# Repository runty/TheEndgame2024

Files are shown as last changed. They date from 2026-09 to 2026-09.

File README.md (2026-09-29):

# Endgame — nice!nano wireless / Choc V1 & V2

A 36-key wireless adaptation of [OldMan6955's Endgame](https://github.com/OldMan6955/TheEndgame2024), using **nice!nano v2**, Choc V1/V2 hot-swap switches, a directly soldered **401730 battery**, and one **WS2812B-V6 status LED**.

The current revision is **4 mm wider than the original PCB**. Each key half moves outward 2 mm, giving the inner keys more clearance from the controller while preserving the original outer borders. The controller, battery opening, and LED remain on the board's centreline. The matching case is wider but retains the original height and sloped profile.

**Status:** verified digital prototype. Electrical, manufacturing-file, and CAD checks pass; physical assembly and electrical operation have not been tested. The current Gerber package has not been verified in JLCPCB's upload preview.

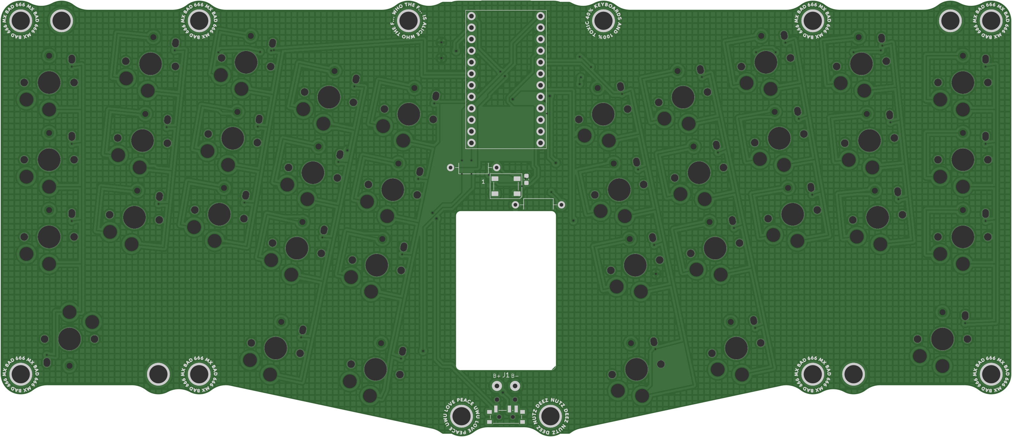
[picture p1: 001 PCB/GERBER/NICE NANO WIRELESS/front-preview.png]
Current PCB, front


## Downloads

Use the PCB, case, and firmware from this table together. The original case and the older XIAO/wired files are separate revisions.

| File | Download |
| --- | --- |
| JLCPCB manufacturing package | [223 mm through-hole-resistor Gerber ZIP](001%20PCB/GERBER/NICE%20NANO%20WIRELESS/TheEndgame2024_NiceNano_223mm_THT_JLCPCB.zip) |
| Widened case | [STL](002%20CASE/NICE%20NANO%20WIRELESS/TheENDGAME2024_NICE_NANO_CASE.stl) · [STEP](002%20CASE/NICE%20NANO%20WIRELESS/TheENDGAME2024_NICE_NANO_CASE.step) |
| Removable battery tray | [STL](002%20CASE/NICE%20NANO%20WIRELESS/TheENDGAME2024_NICE_NANO_BATTERY_TRAY.stl) · [STEP](002%20CASE/NICE%20NANO%20WIRELESS/TheENDGAME2024_NICE_NANO_BATTERY_TRAY.step) |
| Editable KiCad project | [PCB](001%20PCB/KICAD/NICE%20NANO%20WIRELESS/TheEndgame2024_NiceNano.kicad_pcb) · [schematic](001%20PCB/KICAD/NICE%20NANO%20WIRELESS/TheEndgame2024_NiceNano.kicad_sch) · [project and local libraries](001%20PCB/KICAD/NICE%20NANO%20WIRELESS/) |
| nice!nano v2 firmware | [UF2](003%20FIRMWARE/zmk-endgame-nice-nano/firmware/endgame-nice-nano-v2.uf2) · [ZMK source](003%20FIRMWARE/zmk-endgame-nice-nano/) |
| Build details | [Full BOM and assembly notes](docs/nice-nano-wireless.md) · [electrical](docs/nice-nano-electrical.md) · [case](docs/nice-nano-case.md) · [firmware](docs/nice-nano-firmware.md) |

## JLCPCB order settings

| Setting | Value |
| --- | --- |
| Dimensions to enter | **223.00 × 96.11 mm** |
| Layers | **2** |
| Material | **FR-4** |
| Board thickness | **1.6 mm** |
| Copper weight | **1 oz** |

The measured Gerber outline is **223.000032 × 96.106067 mm**. Upload the ZIP intact: it contains the seven board layers, separate plated/non-plated drill files, and the Gerber job file. The **22 × 35 mm battery opening** is included as an internal routed contour. If dimensions need to be entered manually, use the rounded values above and check the board outline and battery opening in the preview.

## Fit and clearance

| Feature | Current design |
| --- | --- |
| Key field | 36 Choc V1/V2 hot-swap positions; each half moved outward 2 mm |
| Outer left/right 1U cap borders | **2.00 mm**, matching the original PCB with 17.5 × 16.5 mm caps |
| Keycap-to-controller clearance | **2.16 mm minimum** to the conservative 18 × 33 mm nice!nano envelope in CAD |
| Printed case width | **231 mm**, with the original overall height retained |
| Battery opening | **22 × 35 mm**, with 1 mm corner radii |
| Battery allowance checked | **18.5 × 33 × 5 mm** complete-pack envelope |

A centred **17 × 30 mm** battery leaves **2.5 mm on each side of the PCB opening**. The larger checked pack envelope leaves **1.75 mm per side and 1.0 mm at each end**, with **0.15 mm above the 5 mm-thick envelope** inside the case after the planned 0.2 mm support allowance. The actual wrapped battery and its lead exit still need measurement.

All 36 nominal **17.5 × 16.5 mm Chicago Steno 1U keycap envelopes** clear the case throughout a full-height CAD sweep, with a **0.70 mm minimum gap**. Choc V2 requires **MX-stem** keycaps. Larger thumb caps and actual print tolerances are not established by this rectangular-envelope check.

See the [measured layout and centreline](docs/validation/nice-nano-pcb/outer-key-symmetry.png), [keycap clearance comparison](docs/validation/nice-nano-case/cs-clearance.png), and [case preview](002%20CASE/NICE%20NANO%20WIRELESS/case-and-tray-preview.png).

## Electronics and assembly

- **nice!nano v2:** mount on short soldered posts, with USB facing the upper edge. Follow the [assembly-height limits](docs/nice-nano-case.md); standard sockets have not been qualified for this case.
- **Battery:** generic 401730 single-cell LiPo, target capacity ≤200 mAh. Solder its wires directly to **J1: pad 1 B+, pad 2 B−**. No JST connector is used. SW38 remains the physical battery disconnect.
- **Resistors:** R1 **330 Ω** and R2 **100 kΩ**, ordinary **¼ W axial through-hole** parts. Use nominal 6.3 × 2.5 mm bodies at **10.16 mm lead pitch**, mounted flat on the PCB's top side. The case accommodates bodies up to 6.5 × 2.5 mm; installation and lead-trimming limits are in the [BOM](docs/nice-nano-wireless.md#parts-and-assembly).
- **Status LED:** one **Worldsemi WS2812B-V6**, powered through nice!nano v2 switched VCC. The translucent case roof acts as the diffuser. The firmware adapts [zmk-rgbled-widget](https://github.com/caksoylar/zmk-rgbled-widget) for brief battery and Bluetooth/USB status flashes, then switches LED power off. See [LED meanings and limits](docs/nice-nano-firmware.md#status-indications).
- **Other parts:** C1 remains a **100 nF 0603 capacitor**, and the matrix retains **36 SOD-123 diodes and 36 Choc hot-swap sockets**. This is a hot-swap switch design; the original optional direct-solder switch pattern is not retained.

The [full parts list](docs/nice-nano-wireless.md#parts-and-assembly) includes controller posts, inserts, tray screws, feet, battery-fit assumptions, and charging requirements. Firmware is **ZMK for nice!nano v2**; the original wired QMK/Vial firmware does not apply to this revision.

## Verification

- **KiCad ERC, DRC, and schematic parity:** zero reported violations or unconnected items under the recorded rules. [ERC](docs/validation/nice-nano-schematic/erc.json) · [DRC](docs/validation/nice-nano-pcb/drc.json)
- **Independent Gerber parsing:** seven board layers, **226 plated and 148 non-plated holes/slots**, both contours closed, and drill registration checked against the PCB source. [Report](docs/validation/nice-nano-pcb/gerbers.json)
- **Mechanical checks:** mirrored key placement, preserved outer borders, centred electronics, valid single-solid STEP parts, watertight STL files, and component/keycap clearance checks. [Spacing](docs/validation/nice-nano-pcb/spacing.json) · [case](docs/validation/nice-nano-case/geometry.json)
- **Firmware:** pinned ZMK build and LED encoder host checks pass. Hardware timing, charging, RF, and full keyboard operation remain untested. [Build and bring-up notes](docs/nice-nano-firmware.md)

The committed PCB is the authoritative manufacturing source. The scratch PCB generator is not a replacement for the finished routing. The [artifact manifest](docs/validation/nice-nano-artifacts.json) records source and output checksums.

## Earlier revisions

| Revision | Details |
| --- | --- |
| XIAO nRF52840 wireless prototype | [Handoff, files, and assembly notes](docs/xiao-wireless.md); 219 × 96.11 mm PCB with a different controller and case |
| Wired Choc V1/V2 conversion | [Compatibility and manufacturing notes](docs/choc-v1-v2.md); original mounting geometry and case |
| Original Endgame | [Upstream project](https://github.com/OldMan6955/TheEndgame2024); original author documentation preserved below |

<details>
<summary>Original upstream README — wired Endgame, parts, credits, and photos</summary>

The following is the original project's documentation. Its controller, firmware, parts lists, manufacturing comments, and physical-test statements refer to the original wired design, not the nice!nano revision above.

TheEndgameBillboard

## Who the F... is Alice ##

Inspired by the legendary TGR Alice, the ENDGAME pays homage to a true classic. While it might not claim the top spot for ergonomics, it's design speaks for itself an iconic piece you’ll want to show off, even if it takes a bit of time for your fingers to adjust.

This low profile keyboard is built for high performance typing. Its slightly staggered layout works beautifully for both ergonomic beginners and experienced users. The unique bottomless top mount design makes it incredibly slim, lightweight, and perfect for those on the move.

## Everything You Need, All In One Place ##

Get the entire kit from KeebSupply, a trusted vendor with affordable international shipping. It’s your one stop shop for everything you need highly recommended! [Buy here](https://keeb.supply/products/endgame) 

For an excellent build guide, check out this fantastic resource from KeebSupply. I haven’t had the time to create my own guide (and honestly, I couldn’t top this one). Big thanks to @KeebSupply! [Build Guide and Supplies](https://docs.keeb.supply/endgame/) 

## PARTS LIST PCB ##

- 1x The Endgame PCB             [Gerber Files](https://github.com/OldMan6955/TheEndgame2024/tree/main/001%20PCB) 

There are now two versions of the PCB:
1.	COPPER Version:
In this version, all design elements are on the copper and mask layers. I used this version to create my prototypes. However, this version has longer loading times, and the Gerber files currently don’t work with JLCPCB. (I’d greatly appreciate any help with troubleshooting this issue.)
2.	SILKSCREEN Version:
This version is untested. All design elements have been moved to the silkscreen layer, making it much more performant on less powerful PCs. The Gerber files display correctly on JLCPCB but have not yet been tested.
Please always test the files yourself to rule out potential errors. Thank you!

- 36x Choc v1 Hotswap Sockets    [buy here](https://www.aliexpress.com/item/1005004916925259.html?) 
- 36x Diodes SOD123 / 1N4148W T4 [buy here](https://de.aliexpress.com/item/1005004309686841.html?) 
- 1x Waveshare RP2040 UGLY AF    [buy here](https://de.aliexpress.com/item/1005006354505058.html?) 

or get the better looking thingy, highly recommended

- | 01 | 0xCB Gemini             [buy here](https://keeb.supply/products/0xcb-gemini) |

## PARTS LIST FDM CASE ##

- 4x M3 6mm countersunk          [buy here](https://de.aliexpress.com/item/4001199728978.html) 
- 4x M3 5mm flathead             [buy here](https://de.aliexpress.com/item/1005005069968742.html) 

You can choose either countersunk or flathead screws both work well. Countersunk screws automatically align the PCB, while flathead screws allow you to manually align and adjust as needed.
The hole for the heat inserts is 4mm deep, and the PCB is 1.6mm thick, so 5mm screws are a perfect fit. Just double-check how the screw length is measured, as this can vary.

- 4x M3 D4.6mm L3mm Heatinsert   [buy here](https://de.aliexpress.com/item/4000232858343.html) 
- 12x M3 D6.6mm grommet black     [buy here](https://de.aliexpress.com/item/4000712868621.html) 

You’ll need 4 grommets if you’re aiming for a bit of flex or bounce, but you can use up to 12 depending on your preference. They work perfectly as feet and provide excellent grip on my desk. Alternatively, bumpons are a great option too.

## SWITCHES AND KEYCAPS ##

Switches

I highly recommend the Choc v1 Silent switches, such as [Nocturnal](https://keeb.supply/products/nocturnal-low-profile-switches) or [Twilights](https://keeb.supply/products/twilight-low-profile-switches). If you prefer heavier springs and a bit of tactile feedback but don’t need silence, [Sunset](https://keeb.supply/products/sunset-low-profile-switches) switches are an excellent choice. As for the rest of the Choc v1 lineup, I wouldn’t bother—they’re not worth considering.

Keycaps

My go-to choice is standard [MBK](https://keeb.supply/products/mbk-keycaps) keycaps, but personal preference always plays a role. For your setup, you’ll need:

- 30x 1U keycaps for the alpha keys (or 28x 1U and 2x 1U homing keycaps)
- 4x 1.5U and 2x 1U convex keycaps for the bottom row

Check with your local vendor, they’re in stock almost everywhere these days. A great way to test switches and keycaps is by attending meetups, there might be an active community near you.

## FIRMWARE - QMK AND VIAL ##

The firmware, expertly created by [dreipunkteinsvier](https://github.com/dreipunkteinsvier), is available for download: [Get it here](https://github.com/OldMan6955/TheEndgame2024/tree/main/003%20FIRMWARE) 
Huge thanks to him, I’d have been completely lost without his help!

## DISCLAIMER ##

This keyboard is an open-source project, and all files are provided free of charge for personal use. While these files have been tested and worked for me, they are provided without any guarantees or warranties of any kind.

By using these files, you agree to take full responsibility for verifying their suitability for your needs. Any orders, modifications, or reproductions made based on these files are done at your own risk. I am not liable for any issues, damages, or losses that may arise from the use of these files or the assembly of the keyboard.

Please ensure you carefully review all files and specifications before proceeding. Thank you for understanding!

## RANDOM PEOPLE I KNOW ##

After three years of development and collaboration with contributors from around the world, the ENDGAME is more than just a keyboard it’s the result of a shared journey, a community driven effort that reflects the passion and creativity of everyone involved.

- [Marco "Bob"](https://github.com/GroooveBob) - for answering all my dumb questions 24/7
- [dreipunkteinsvier](https://github.com/dreipunkteinsvier) - firmware and stupid github
- [bubbleology](https://github.com/bubbleology) - inspiration, CAD and emotional support
- [GEIST](https://github.com/GEIGEIGEIST) - can't remember what, but we talked about stuff back in the days RIP
- MY WIFE - for reasons
- and many more

To all who contributed thank you. Enjoy the journey, and have fun exploring what this keyboard can do!

## PICTURES ##

TheEndgameMood
TheENDGAME front
TheENDGAME back

## ONLY FANS ##

While this project is free and open source, I truly appreciate your support. If you'd like to contribute, feel free to leave a tip via Ko-fi to help support future projects. Thank you!

 

## SHARE YOUR BUILDS ##

Do you love your ENDGAME? I’d love to see your builds! Join the Discord community to share pictures of your keyboards and chat with fellow enthusiasts.
Just a heads-up: I can’t help with technical issues or soldering nightmares because I’m still learning myself. So, please don’t ask me for help with that!



## FINAL WISDOM ##

    "The worst thing that can happen is someone calling me a keyboard designer."
    -OLDMAN6955

</details>

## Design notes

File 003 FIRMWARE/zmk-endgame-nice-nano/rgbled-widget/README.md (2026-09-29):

# Endgame RGB LED widget adapter

This directory vendors the event and behavior code from
[caksoylar/zmk-rgbled-widget](https://github.com/caksoylar/zmk-rgbled-widget)
at commit `e6b467792a1dabef8cfa5c9fd26bfefc9c16662b` (MIT; see `LICENSE`).
The upstream shield and its GPIO LED definitions are omitted because Endgame
uses one switched-supply WS2812B-V6 pixel.

The local patch in `src/widget.c` replaces the three-channel GPIO LED backend
with `endgame_status_pulse()` and `endgame_status_cancel()`. The original event
listeners, status selection, message queue, threads, and on-demand behaviors are
retained. Durations are capped at 500 ms before the API call; the pulse API also
caps each color channel at 25/255 and rejects flashes while sleeping or when
the measured supply is below 3600 mV. The adapter rejects persistent layer
colors at compile time. `Kconfig` no longer enables the unused GPIO LED driver.

To update upstream, compare this directory against the pinned commit before
reapplying the backend adaptation. The build copies this directory into its
staging workspace and passes it to ZMK as an extra module.

The host color mapping check is:

```sh
cc -std=c11 -Wall -Wextra -Werror -I rgbled-widget/include \
  rgbled-widget/tests/color_test.c -o /tmp/endgame-color-test
/tmp/endgame-color-test
```

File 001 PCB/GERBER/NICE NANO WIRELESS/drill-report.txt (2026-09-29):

Drill report for TheEndgame2024_NiceNano.kicad_pcb
Created on 2026-09-29T09:10:03

Copper Layer Stackup:
    =============================================================
    L1 :  F.Cu                      front
    L2 :  B.Cu                      back

Drill file 'TheEndgame2024_NiceNano-PTH.drl' contains
    plated through holes:
    =============================================================
    T1  0.300mm  0.0118"  (23 holes))
    T2  0.300mm  0.0118"  (36 holes))
    T3  0.400mm  0.0157"  (13 holes))
    T4  0.800mm  0.0315"  (4 holes))
    T5  1.000mm  0.0394"  (26 holes))
    T6  1.270mm  0.0500"  (36 holes))
    T7  3.000mm  0.1181"  (72 holes))
    T8  4.000mm  0.1575"  (16 holes))

    Total plated holes count 226

Drill file 'TheEndgame2024_NiceNano-NPTH.drl' contains
    unplated through holes:
    =============================================================
    T1  0.900mm  0.0354"  (2 holes))
    T2  1.000mm  0.0394"  (2 holes))
    T3  1.500mm  0.0591"  (36 holes)  (with 36 slots)
    T4  1.700mm  0.0669"  (72 holes))
    T5  5.000mm  0.1969"  (36 holes))

    Total unplated holes count 148

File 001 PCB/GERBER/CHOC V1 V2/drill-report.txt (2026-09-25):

Drill report for TheENDGAME2024_SILKSCREEN.kicad_pcb
Created on 2026-09-25T16:52:41

Copper Layer Stackup:
    =============================================================
    L1 :  F.Cu                      front
    L2 :  B.Cu                      back

Drill file 'TheENDGAME2024_SILKSCREEN-PTH.drl' contains
    plated through holes:
    =============================================================
    T1  0.300mm  0.0118"  (8 holes))
    T2  0.300mm  0.0118"  (36 holes))
    T3  0.400mm  0.0157"  (13 holes))
    T4  1.270mm  0.0500"  (36 holes))
    T5  3.000mm  0.1181"  (72 holes))
    T6  4.000mm  0.1575"  (16 holes))

    Total plated holes count 181

Drill file 'TheENDGAME2024_SILKSCREEN-NPTH.drl' contains
    unplated through holes:
    =============================================================
    T1  1.500mm  0.0591"  (36 holes)  (with 36 slots)
    T2  1.700mm  0.0669"  (72 holes))
    T3  5.000mm  0.1969"  (36 holes))

    Total unplated holes count 144

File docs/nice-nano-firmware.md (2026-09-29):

# Endgame nice!nano v2 firmware

The buildable ZMK configuration is in [`003 FIRMWARE/zmk-endgame-nice-nano`](../003%20FIRMWARE/zmk-endgame-nice-nano). It targets **nice!nano v2** (`nice_nano//zmk`, board revision 2.0.0) and the revised Endgame PCB with 36 Choc V1/V2 switch positions, one WS2812B-V6 status LED, and no 74HC595. The original XIAO configuration remains separate.

## Matrix and keymap

The shield uses ZMK's stock `zmk,kscan-gpio-matrix` with COL2ROW diodes, four direct rows, ten direct columns, and the existing 36-position transform. The keymap file is byte-for-byte identical to the old ZMK keymap. No key binding is reassigned to the LED; automatic status indications run independently of the keymap.

| Matrix signal | nice!nano D pin | nRF52840 pin |
| --- | ---: | --- |
| Row 0 | D6 | P1.00 |
| Row 1 | D7 | P0.11 |
| Row 2 | D8 | P1.04 |
| Row 3 | D9 | P1.06 |
| Col 0 | D0 | P0.08 |
| Col 1 | D2 | P0.17 |
| Col 2 | D3 | P0.20 |
| Col 3 | D4 | P0.22 |
| Col 4 | D5 | P0.24 |
| Col 5 | D21 | P0.31 |
| Col 6 | D20 | P0.29 |
| Col 7 | D19 | P0.02 |
| Col 8 | D18 | P1.15 |
| Col 9 | D15 | P1.13 |

The bottom row has positions `RC(3,0)`, `RC(3,3)`, `RC(3,4)`, `RC(3,5)`, `RC(3,6)`, and `RC(3,9)`; these retain Left Shift, Lower/Escape, Return, Space, Raise/Delete, and Right Shift.

## Status pixel

The PCB has one WS2812B-V6 behind the translucent case; no dedicated case opening is needed. Its DIN is on **D1/P0.06** through 330 Ω, with a 100 kΩ pulldown on DIN. Its VDD is on nice!nano v2 switched VCC, decoupled with 100 nF next to the LED. **P0.13 high enables that rail; low disables it.** Firmware disables ZMK's stock persistent `EXT_POWER` node and drives P0.13 low at startup. DIN is also driven low when the LED is unpowered to avoid phantom power through the input pin.

SPI3 is used only to send the WS2812 data on P0.06. A dedicated V6 encoder packs twenty samples per bit at 16 MHz: zero is 312.5 ns high / 937.5 ns low, one is 625 ns high / 625 ns low, and every bit lasts 1.25 µs. It waits 300 µs after each frame and 1 ms after enabling power, then initializes the pixel to black before a pulse. These values match the selected V6 datasheet; the generic four-megahertz WS2812 example is not used. A host test decodes 258 encoded frames and verifies GRB order, high/low pulse widths, and final data-low state. Its stock 74HC595 SPI IRQ patch is neither copied nor applied. ZMK RGB underglow is disabled, so there is no animation, stored on-state, or persistent LED supply.

[`status_pulse.h`](../003%20FIRMWARE/zmk-endgame-nice-nano/status-pulse/include/endgame/status_pulse.h) exposes `endgame_status_pulse(red, green, blue, duration_ms)` and `endgame_status_cancel()` for the widget output adapter and explicit test pulses. Each RGB channel is capped at 25/255 (under 10%); a zero duration uses 100 ms and any requested duration is capped at 500 ms. A fresh voltage reading below 3.6 V suppresses a pulse; sensor failure also suppresses it. The pulse is rejected during sleep, canceled on sleep or device suspend, and cut off after errors or explicit cancellation. This 3.6 V threshold is provisional headroom for the LED's 3.3 V minimum. The battery sensor reads nice!nano VDDH, **not the switched LED rail**; measure LED VDD on the assembled board before treating the threshold as electrically validated.

The behavior node `&status_pulse` is compiled but intentionally unbound. To test it on hardware, temporarily replace an expendable Raise-layer binding such as `&kp F12` in `config/endgame.keymap` with `&status_pulse`, rebuild, press that key while holding Raise, and then restore the keymap. It sends a dim amber 100 ms pulse. Automatic status meanings are supplied by the widget described below.

## Status indications

This revision uses [caksoylar/zmk-rgbled-widget](https://github.com/caksoylar/zmk-rgbled-widget), adapted for the board's single addressable pixel. Upstream normally drives three separate GPIO LED channels; the Endgame adapter routes its colour requests through the existing WS2812B-V6 pulse driver. The widget supplies the battery and connection event logic. This requires no PCB changes.

| Event | Flash meaning |
| --- | --- |
| Boot: battery indication | Green at ≥80%, yellow at 20–79%, red below 20%; magenta if the battery percentage is unavailable |
| Boot, Bluetooth profile change, or selected endpoint change | Blue for connected Bluetooth, yellow for an open advertising profile, red for no connection, cyan when USB is selected |
| Battery state update at 1–5% | Requests a red critical-battery flash, subject to the voltage cutoff below |

**The 3.6 V cutoff applies to every colour and every event.** Red low/critical-battery flashes, and the missing-battery indication, can therefore be suppressed. Do not rely on the pixel as an empty-battery warning. This is intentional until the assembled LED supply is measured; it is not a change to the widget's battery-percentage thresholds.

Battery and connection flashes last **120 ms**, with a **150 ms** gap between queued indications. There is no continuous lighting. Automatic layer indications and persistent layer colours are disabled. The existing keymap is retained. To add an on-demand check later, include `<behaviors/rgbled_widget.dtsi>` in `config/endgame.keymap` and assign `&ind_bat` or `&ind_con` to a chosen position; those checks use the same power and voltage limits.

## Build and flash

Run `003 FIRMWARE/zmk-endgame-nice-nano/build.sh` from the repository or any working directory. The script uses the existing `/tmp/endgame-zmk-workspace` dependency tree and pinned ZMK commit `5b51501fead672c41b5cfb396f3dafe0894bf4e9`. It extracts a clean archive of that commit into a separate temporary source tree and builds in `/tmp/endgame-zmk-workspace/build/endgame-nice-nano`. This isolates the build from the XIAO source's local IRQ patch. The widget is vendored with its MIT licence at upstream commit `e6b467792a1dabef8cfa5c9fd26bfefc9c16662b`, with a local WS2812 output adapter; it is not downloaded from a moving branch during builds. The script stages the config and both modules under a path without spaces because ZMK's devicetree overlay list splits a path containing `003 FIRMWARE`.

The output is [`endgame-nice-nano-v2.uf2`](../003%20FIRMWARE/zmk-endgame-nice-nano/firmware/endgame-nice-nano-v2.uf2). Double-tap reset on nice!nano v2 and copy the UF2 to its bootloader drive. A successful clean compile is recorded in [`build.log`](../003%20FIRMWARE/zmk-endgame-nice-nano/firmware/build.log). The UF2 SHA-256 is:

```text
f5662f0993dc97762743c5ac36d98072a58d338cdeca31086cd5abc1d131457a
```

Host tests also verify the adapter maps all eight widget colours to the intended dim RGB channels. The build proves that the pinned source, devicetree, keymap, widget, pulse module, and target link together. Board-level validation remains: check that P0.13 and LED VDD return low after the boot indication sequence and each pulse, DIN is low while VDD is off, all 36 matrix positions register once, BLE/USB work, and the LED is visible through the case. Measure the LED rail at low battery and during USB charging before choosing a final cutoff.

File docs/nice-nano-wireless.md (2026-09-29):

# Endgame nice!nano / 401730 prototype handoff

The nice!nano v2 revision retains all **36 Choc V1/V2 hot-swap keys**, uses a central **22 × 35 mm battery opening** for the user's generic 401730 pack, and adds one **WS2812B-V6 status pixel**. The battery wires solder directly to J1; SW38 remains at the preferred location. The case is 4 mm wider to match the shifted keys, while retaining the original sloped profile and overall height, with deeper internal pockets. The controller hood and side shoulders were removed after a full-height cap-envelope check found interference with adjacent keycap envelopes.

The schematic, routed PCB, fabrication export, printable case/tray, and ZMK firmware are complete as a **digital prototype**. Physical assembly, charging, RF, and LED operation have not been tested. This archive has not been uploaded to or previewed by JLCPCB.

## Files

| Deliverable | File |
| --- | --- |
| JLCPCB fabrication archive | [TheEndgame2024_NiceNano_223mm_THT_JLCPCB.zip](../001%20PCB/GERBER/NICE%20NANO%20WIRELESS/TheEndgame2024_NiceNano_223mm_THT_JLCPCB.zip) |
| Editable circuit and layout | [Schematic](../001%20PCB/KICAD/NICE%20NANO%20WIRELESS/TheEndgame2024_NiceNano.kicad_sch), [PCB](../001%20PCB/KICAD/NICE%20NANO%20WIRELESS/TheEndgame2024_NiceNano.kicad_pcb), project-local NanoWireless libraries |
| Printable case | [STL](../002%20CASE/NICE%20NANO%20WIRELESS/TheENDGAME2024_NICE_NANO_CASE.stl), [STEP](../002%20CASE/NICE%20NANO%20WIRELESS/TheENDGAME2024_NICE_NANO_CASE.step) |
| Removable battery tray | [STL](../002%20CASE/NICE%20NANO%20WIRELESS/TheENDGAME2024_NICE_NANO_BATTERY_TRAY.stl), [STEP](../002%20CASE/NICE%20NANO%20WIRELESS/TheENDGAME2024_NICE_NANO_BATTERY_TRAY.step) |
| Case inspection views | [Side profile against original](../002%20CASE/NICE%20NANO%20WIRELESS/case-side-profile.png), [case and tray](../002%20CASE/NICE%20NANO%20WIRELESS/case-and-tray-preview.png) |
| Prototype nice!nano v2 firmware | [UF2](../003%20FIRMWARE/zmk-endgame-nice-nano/firmware/endgame-nice-nano-v2.uf2), [source and build script](../003%20FIRMWARE/zmk-endgame-nice-nano/) |
| Manufacturing previews | [Front](../001%20PCB/GERBER/NICE%20NANO%20WIRELESS/front-preview.png), [back](../001%20PCB/GERBER/NICE%20NANO%20WIRELESS/back-preview.png) |

Order the PCB as **2 layers, 1 oz copper, 1.6 mm FR-4**, **223 × 96.11 mm**. The ZIP contains one board: seven graphic layers, separate plated and non-plated Excellon drills, and a Gerber job file. The centre battery opening is a routed internal contour. A short 0.127 mm matrix trace beside R2 is within the [JLCPCB 1 oz capability](https://jlcpcb.com/capabilities/pcb-capabilities) of 0.10 mm minimum width; select 1 oz copper for this export. Upload the ZIP intact; inspect the outer shape, battery opening, and holes in the manufacturer's preview before ordering. The older wired RP2040 and XIAO archives are different designs.

The nice!nano body and header rows, battery opening, and LED body share **PCB X=150.00 mm**, the left/right centreline of the board. Their front/back positions remain separate. The PCB is 4 mm wider, and each key half moves 2 mm outward: the outer left and right 1U keycap borders both measure **2.00 mm** using centred 17.5 × 16.5 mm caps. Choc's offset locating slot makes the drill artwork look asymmetric; the slot is not the key centre. See the [measured border comparison](validation/nice-nano-pcb/outer-key-symmetry.png).

## Validation

KiCad **10.0.6** reports **zero ERC violations, zero DRC violations, zero unconnected items, and zero schematic-parity issues**, under the rule settings recorded in the reports, including a 0.10 mm minimum track width for 1 oz manufacturing. The manufacturing export uses the [JLCPCB KiCad guide](https://jlcpcb.com/help/article/how-to-generate-gerber-and-drill-files-in-kicad-9): RS-274X layers with a shared absolute origin, separate drill types, and silkscreen clipped against solder-mask openings.

- [Source geometry/netlist report](validation/nice-nano-pcb/geometry.json): all 36 switches and diodes move exactly 2 mm outward by half, retaining their rotations, footprints, relative pad geometry, and nets; the exterior profile is widened by 4 mm around the fixed centre section; 183 terminals match the schematic XML.
- [Independent Gerber report](validation/nice-nano-pcb/gerbers.json): Gerbonara 1.6.3 parses all seven graphic layers and **226 plated + 148 non-plated holes/slots**, registered to source within 0.002 mm. Both contours are closed. Measured exterior: 223.000032 × 96.106067 mm.
- [DRC](validation/nice-nano-pcb/drc.json), [ERC](validation/nice-nano-schematic/erc.json), and [schematic PDF](validation/nice-nano-schematic/schematic.pdf).
- [Case report](validation/nice-nano-case/geometry.json): valid single-solid STEP parts and watertight STL meshes; the case's maximum height matches the original. All 36 conservative switch-body envelopes clear it, with a 1.6 mm minimum gap. A nominal 17.5 × 16.5 mm CS envelope swept from PCB top through Z=20 clears all 36 locations, with a 0.70 mm minimum gap; this is a rectangular CAD envelope check, not physical print proof or a check of larger thumb caps. See the [CS clearance preview](validation/nice-nano-case/cs-clearance.png), [clearance data](validation/nice-nano-case/cs-clearance.json), and [case notes](nice-nano-case.md). Choc V2 needs MX-stem CS caps; the linked [Asymplex CS Choc page](https://www.asymplex.xyz/product/cs-chicago-stenographer-profile) describes Choc V1 stems.
- [Firmware build log](../003%20FIRMWARE/zmk-endgame-nice-nano/firmware/build.log): pinned ZMK commit `5b51501fead672c41b5cfb396f3dafe0894bf4e9`, nice!nano v2. The original keymap is retained; the V6 encoder's host test verifies 258 frames. Hardware pulse timing still needs measurement.

The [spacing report](validation/nice-nano-pcb/spacing.json) checks the widened perimeter, retained key borders, central alignment, and clearance between the inner keys and the controller.

The final PCB is authoritative. `tools/build_nice_nano_pcb.py` creates only a scratch placement with retained routes, and deliberately refuses to overwrite the finished PCB. `tools/build_nice_nano_case.py` regenerates and verifies the case outputs.

## Parts and assembly

| Qty | Part | Assembly note |
| ---: | --- | --- |
| 1 | nice!nano **v2** | USB faces the top edge; mount on short individually soldered posts with a height-setting jig. |
| 24 | Straight solder posts | Complete module, including USB shell and underside projections, must fit within Z=2.6…6.0 mm, relative to PCB bottom Z=0. Standard sockets have not been qualified. |
| 1 | Generic 401730 single-cell LiPo | User-supplied pack, nominal target ≤200 mAh. Full taped-pack size and allowed charge rate remain unverified. Direct-wire J1: pad 1 B+, pad 2 B−; retain strain relief. |
| 1 | PCM12SMTR slide switch | SW38; must be on to connect the battery to the nice!nano for charging. |
| 1 | **Worldsemi WS2812B-V6**, 5050 four-pad | LED1, top side, with pin 1 aligned to the PCB marker. Select this 3.3 V-capable revision. |
| 1 | 100 nF ceramic capacitor, 0603 | C1, ≥6.3 V rating; local LED supply bypass. |
| 1 each | 330 Ω and 100 kΩ resistors, ¼ W axial through-hole | R1 series DIN resistor; R2 DIN pulldown. Nominal body 6.3 × 2.5 mm, horizontal 10.16 mm lead pitch, 0.8 mm plated holes. |
| 36 each | Choc V1/V2 switches, Choc hot-swap sockets, 1N4148W SOD-123 diodes | Retained key field. |
| 6 | M3 D4.6 × 3 mm heat-set inserts | Four original case mounts plus two tray mounts. |
| 2 | M3 × 6 mm, 90° countersunk tray screws | Recessed tray-ear heads; retain the four original outer case screws. |
| 4 or more | Feet/bumpons | Installed projection ≥1 mm below the original case support plane, to clear tray and screw heads. |

The insulating tray and internal battery recess use an **18.5 × 33 × 5 mm pack proxy**, not a measured maximum for the user's pack. Measure the complete pack and lead exit before printing/ordering. Mount the nice!nano level, keep its lowest underside projection at least 1 mm above the host PCB top, and measure the entire installed module envelope before closing the case. The [case notes](nice-nano-case.md) detail the assembly datum, recesses, USB access, fasteners, and fit assumptions.

Install R1 and R2 lying flat on the top side, with bodies no larger than 6.5 mm long × 2.5 mm diameter and no more than 0.2 mm above the PCB. Trim their soldered leads to at most 0.8 mm below the PCB underside. The revised case has internal pockets for their bodies and leads and retains its original exterior height. C1 remains a 0603 capacitor.

Leave the nice!nano charge-boost jumper open for its ordinary nominal **100 mA** charging setting, and verify suitability for the actual cell. There is no external charger or matrix-expander chip. The pixel uses nice!nano v2 switched VCC and P0.06 through R1; firmware keeps its power off between events. The shipped keymap has no LED bindings. An adapted zmk-rgbled-widget supplies automatic battery and Bluetooth/USB status flashes; see [firmware notes](nice-nano-firmware.md). Electrical pin mapping and component orientation are in the [electrical notes](nice-nano-electrical.md).

Before treating this as proven hardware, verify controller/USB/pack fit, keycap travel, all 36 keys, BLE and USB, idle/sleep wake, charging current, and LED DIN/VCC behavior on the first assembly. This is the remaining prototype validation, not work established by CAD or compilation.

## Checksums

Gerber ZIP SHA-256: `25c72831301f0641045401afa0cec08d2440b7e30919f5c405f65c11e87c0e7b`

PCB source SHA-256: `e5223e848921047923474be2aa05235f5087fc120c3f9a9fd1052ff5834562f4`

UF2 SHA-256: `f5662f0993dc97762743c5ac36d98072a58d338cdeca31086cd5abc1d131457a`

The [artifact manifest](validation/nice-nano-artifacts.json) records all source/output checksums and the baseline revision.

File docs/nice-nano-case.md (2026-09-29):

# Endgame nice!nano / 401730 case prototype

The revised case and removable battery tray are generated from the original Endgame STEP with [`tools/build_nice_nano_case.py`](../tools/build_nice_nano_case.py). Run it with `/tmp/endgame-fit-env/bin/python tools/build_nice_nano_case.py` or another Python environment containing OCP, trimesh, Matplotlib, and NumPy. The original STEP and the separate XIAO variant are unchanged. The new [case STEP](../002%20CASE/NICE%20NANO%20WIRELESS/TheENDGAME2024_NICE_NANO_CASE.step), [case STL](../002%20CASE/NICE%20NANO%20WIRELESS/TheENDGAME2024_NICE_NANO_CASE.stl), [tray STEP](../002%20CASE/NICE%20NANO%20WIRELESS/TheENDGAME2024_NICE_NANO_BATTERY_TRAY.step), [tray STL](../002%20CASE/NICE%20NANO%20WIRELESS/TheENDGAME2024_NICE_NANO_BATTERY_TRAY.stl), and [mesh preview](../002%20CASE/NICE%20NANO%20WIRELESS/case-and-tray-preview.png) are a digital prototype. They have not been printed or assembled.

Coordinates below use `(PCB X − 150, 140 − PCB Y, Z)` in millimetres. The 1.6 mm PCB occupies `Z=0…1.6`; the case sits above it. The original sloped exterior and overall height are retained. Deeper internal pockets make room for the battery and controller. The controller hood and side shoulders have been removed after a full-height cap-envelope check revealed intrusion into adjacent Chicago Stenographer keycap envelopes. The case is widened by 4 mm: the original sections outside case X=±12 mm move outward 2 mm, and matching sections bridge the two resulting gaps. All 36 keys and the outer mounting features move with their halves; the controller, LED, battery opening, central tray mounts, J1 wire landing, and SW38 power-switch access stay fixed. The original keycap-to-outer-edge borders are preserved.

| Feature | Revised geometry and purpose |
| --- | --- |
| Battery opening and case recess | The intended PCB opening is `X=139…161, Y=109…144`, 22 × 35 mm with R1 corners. The case recess spans `X=−11.1…11.1, Y=−4.1…31.1`, R1, to `Z=5.35`. This accommodates a **planning proxy** of 18.5 × 33 × 5 mm at `Z=0.2…5.2`, leaving 0.15 mm vertical headroom. The proxy is **not a measured maximum** for the user's full taped 401730 pack. The complete pack, lead exit, and swelling allowance require physical measurement. |
| Wire and switch access | The existing `X=−3.4…3.4, Y=−11.1…−3.6` lead channel reaches the J1 pads at PCB `(148,147.5)` and `(152,147.5)` and relief holes at `Y=150.5`. The SW38 slider tunnel at case `Y≈−22.3…−12.4` is retained. There is no battery connector. |
| Status LED clearance | A local pocket at case `X=−6.7…6.2, Y=33.0…40.2` to `Z=3.55` clears the top-side WS2812B-V6 LED centred at PCB `(150,103.5)` and its adjacent 0603 capacitor. The exterior roof stays intact for diffusion through translucent PLA; there is no LED window or separate diffuser. |
| Through-hole resistor clearance | R1 and R2 lie flat on top of the PCB at body centres `(142.85,99.4)` and `(157.15,107.6)`, on opposite sides of the LED. Their body and lead pockets extend to `Z=4.65` and `Z=3.55` respectively. A 6.5 × 2.5 mm body proxy raised 0.2 mm above the PCB clears the roof by 0.35 mm. At least 1.95 mm of roof remains directly above both bodies. The resistor proxies have at least 1.4 mm horizontal separation from the LED; R2 has 1.15 mm front/back separation from the battery planning proxy. |
| Low-post nice!nano cavity | The nominal controller body is assumed to occupy PCB `X=141…159, Y=63…96`. The rounded case cavity is `X=−9.2…9.2, Y=43.2…77.8` to `Z=6.5`. The cavity remains unchanged. No controller hood or side shoulders are added; the stock sloped roof and key-opening contours are retained. The central 16 mm of the controller roof retains at least 1.25 mm over the specified assembly envelope. The narrower side regions follow the original key-opening contour, so there is no uniform 0.8 mm sidewall or 1.25 mm roof claim across the full 18 mm width. |
| USB access | The cable passage is `X=−6.4…6.4, Y=70…82` to `Z=7.3`, open through the upper case edge. The original roof already encloses the required cover envelope `X=−7.4…7.4, Y=69.6…79.7` through `Z=8.55`, leaving at least 1.25 mm roof over the inner plug corridor without increasing the exterior height. Actual cable-head fit is untested. |
| Lower tray | Main insulating plate `X=−12…12, Y=−5…32`, `Z=−1…0`, extended 7 mm with the opening. Two ears reuse the central PCB holes and added D4.6 mm case insert seats. The model accepts recessed M3 × 6 DIN965 countersunk screws; the case needs installed feet projecting at least 1.0 mm below its `Z=−1.4` base plane to keep at least 0.6 mm desk clearance beneath the tray ears. |

**Controller height is an assembly limit.** The case assumes the *entire* nice!nano assembly, including the USB shell and underside projections, fits within `Z=2.6…6.0`. Relative to the host PCB top at `Z=1.6`, this requires the lowest module projection to clear the PCB by at least 1.0 mm and every assembled feature to remain at or below `Z=6.0`. Use short individual soldered posts with a height-setting jig or spacer and measure the completed assembly before enclosure fitting. Standard low-profile sockets have not been qualified for this case: their published above-board height refers to the module-board plane, while the stated module thickness includes projections on both sides, so the two figures cannot simply be added. Any socket installation must independently meet both complete-envelope limits. The actual module revision, posts, USB shell, solder joints, and cable plug were not measured here. The host PCB should keep copper clear beneath the radio antenna.

The generator verifies valid single solids, no case/tray overlap, component proxy clearance, intact battery and LED roofs, the two new insert bores and screw seats, and no collision with the 36 rotated 15 × 15 mm switch-body envelopes. Minimum switch-body clearance is **1.6 mm**. Reimported STEP parts remain valid single solids; both exported STL meshes are watertight and consistently wound. The [geometry report](validation/nice-nano-case/geometry.json) records the mesh volumes and envelope limits.

The earlier static 17 × 17 mm keycap proxy at PCB-bottom `Z=8…13` did not test press clearance: it missed that the controller hood intruded into adjacent keycap space. After removing the hood and restoring the stock roof/opening contours, a full-height sweep of nominal 1U Chicago Stenographer envelopes (17.5 × 16.5 mm, centered on each switch after the 2 mm outward half-shift and rotated with it) from PCB-top `Z=1.6` through `Z=20` clears all 36 locations. Minimum gap is **0.70 mm**, including both circled positions, SW16 and SW20. The widened baseline and finished case give the same reported clearances. The original 227 mm-wide case does not fit the shifted key field; use the new 231 mm-wide case with this PCB. See the [CS clearance preview](validation/nice-nano-case/cs-clearance.png) and [clearance data](validation/nice-nano-case/cs-clearance.json). This is a nominal rectangular-envelope CAD check, not physical print proof or validation of larger thumb caps and sculpted skirts. Choc V2 requires the MX-stem CS variant; the linked [Asymplex CS Choc page](https://www.asymplex.xyz/product/cs-chicago-stenographer-profile) describes Choc V1 stems. Verify actual keycap travel, hot-swap sockets, installed controller height, USB plug, pack, screw seating, and PLA print tolerances on a physical prototype before manufacturing or use.

The [centreline side profile](../002%20CASE/NICE%20NANO%20WIRELESS/case-side-profile.png) overlays the revised section with the original case. Both have the same maximum Z; the original top slopes from roughly 6.6 mm at the front to 10.13 mm at the back. All quoted Z values use the PCB-bottom datum, not thickness measured normal to that sloping surface.

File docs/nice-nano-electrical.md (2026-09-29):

# Endgame nice!nano v2 electrical revision

The editable project is [`TheEndgame2024_NiceNano.kicad_sch`](../001%20PCB/KICAD/NICE%20NANO%20WIRELESS/TheEndgame2024_NiceNano.kicad_sch). It retains the original 36 Choc V1/V2 hot-swap switches and 36 matrix diodes, with four rows and ten columns in **COL2ROW** direction. All ten columns and four rows connect directly to nice!nano v2 GPIO; the XIAO and 74HC595 circuit are absent. `U2` is a nice!nano v2 mounted on short soldered pin posts with USB facing the top of the board. `SW38` remains the physical battery disconnect in its original location; `J1` is a direct-wire battery landing, without a JST connector.

The module pin functions below follow [Nice Keyboards' v2 pinout](https://nicekeyboards.com/docs/nice-nano/pinout-schematic/). The pin-post footprint uses the 24 standard Pro Micro side positions; its pad numbering and 2.54 mm pitch were cross-checked against the [open hardware nice!nano KiCad footprint](https://github.com/bstiq/nice-nano-kicad/blob/master/nice_nano.kicad_mod). The module's separate B+ and B− top solder pads are intentionally **not** populated with posts. [Nice Keyboards instructs](https://nicekeyboards.com/docs/nice-nano/getting-started/) builders to use RAW and GND as their equivalents when those rails are required through a keyboard PCB.

| Net | U2 PCB pad | nice!nano label / nRF pin |
| --- | ---: | --- |
| `col0` | 2 | D0 / P0.08 |
| `col1` | 5 | D2 / P0.17 |
| `col2` | 6 | D3 / P0.20 |
| `col3` | 7 | D4 / P0.22 |
| `col4` | 8 | D5 / P0.24 |
| `col5` | 20 | D21 / P0.31 |
| `col6` | 19 | D20 / P0.29 |
| `col7` | 18 | D19 / P0.02 |
| `col8` | 17 | D18 / P1.15 |
| `col9` | 16 | D15 / P1.13 |
| `row0` | 9 | D6 / P1.00 |
| `row1` | 10 | D7 / P0.11 |
| `row2` | 11 | D8 / P1.04 |
| `row3` | 12 | D9 / P1.06 |
| `LED_DATA` | 1 | D1 / P0.06, high-frequency GPIO |
| `VBAT_SW` | 24 | RAW |
| `VCC_SW` | 21 | VCC, software-switched 3.3 V output |
| `gnd` | 3, 4, 23 | GND |

U2 pads 13–15 (D10, D16, D14) and pad 22 (RST) are marked no-connect. The remaining exposed nRF and control pads on the underside of the module are not used. The original matrix connections are preserved: each switch connects a column to its diode, and each diode cathode is on a row. The netlist contains all 36 such switch and diode paths.

## Battery and LED

`J1.1` receives battery positive on `VBAT`; `J1.2` receives battery negative on `gnd`. `SW38.2` is the positive common and `SW38.1` feeds `VBAT_SW` to U2 RAW. `SW38.3` is unconnected. The slide switch must be on for USB charging of the attached cell. The nice!nano's own charger is the only charger in the design; its charge-boost jumper must remain open for the nominal 100 mA ordinary setting described by [Nice Keyboards](https://nicekeyboards.com/docs/nice-nano/). The user's generic 401730 battery pack has no identified datasheet. Its exact dimensions, protection circuitry, capacity, and allowed charge rate remain **unverified**. Physical and electrical pack verification is required before manufacturing or sustained charging.

`LED1` is one [Worldsemi WS2812B-V6](https://www.world-semi.com/downloads/datasheets/en/ws2812b-v6-1.0.pdf) in the 5050 four-pad package. This specific revision states a 3.3–5.3 V operating range; older WS2812B revisions are not assumed interchangeable. `U2.21` powers only LED1 VDD and its local 100 nF `C1`; LED1 VSS and C1 return to ground. `U2.1` (P0.06) drives LED1 DIN through 330 Ω `R1`. A 100 kΩ `R2` from DIN to ground holds the data input low when the switched VCC is disabled. LED1 DOUT is unconnected. On nice!nano **v2**, [the official pinout](https://nicekeyboards.com/docs/nice-nano/pinout-schematic/) states that P0.13 low cuts VCC off; the firmware must explicitly control that rail and keep DIN low between brief status flashes. The LED's behaviour near battery depletion needs prototype measurement; do not claim normal operation below its published 3.3 V minimum.

## Physical footprint and verification

R1 (330 Ω) and R2 (100 kΩ) use ordinary ¼ W axial through-hole resistors in the project-local `NanoWireless:R_Axial_DIN0207_L6.3mm_D2.5mm_P10.16mm_Horizontal` footprint based on KiCad's standard DIN0207 geometry. The nominal body is 6.3 × 2.5 mm; pad pitch is 10.16 mm, with 1.6 mm pads and 0.8 mm drills. The local courtyard follows the body and pad lands with 0.25 mm clearance, avoiding the standard bounding rectangle's empty corners; the lower silkscreen line is trimmed for the nearby battery cutout. Both mount horizontally on the top side. R1 pad 1 is `(137.77,99.4)` on `LED_DATA`, and pad 2 is `(147.93,99.4)` on `LED_DIN`. R2 pad 1 is `(162.23,107.6)` on `LED_DIN`, and pad 2 is `(152.07,107.6)` on `gnd`. Their body centres are offset to `(142.85,99.4)` and `(157.15,107.6)` for at least 1.4 mm of horizontal body separation from the LED, using a 6.5 mm-long resistor proxy. The nice!nano, LED, and battery opening remain on X=150 mm. The circuit values and firmware are unchanged. Keep the body at most 0.2 mm above the board, use bodies no larger than 6.5 × 2.5 mm, and trim the lead ends to at most 0.8 mm below the PCB underside for case clearance.

The local `NanoWireless:NiceNano_v2_PinPosts` footprint has two rows of twelve 1.8 mm OD / 1.0 mm drill plated holes for individually soldered straight posts. Hold the module level on a jig while soldering, with at least 1.0 mm gap between the host PCB and the *lowest actual module projection*; insulate the underside of the host PCB from the battery. The mechanical planning stack is host top Z=1.6 mm, module low point at or above Z=2.6 mm, and a maximum nominal module envelope of 3.4 mm (the official 3.2 mm plus 0.2 mm allowance), giving a planned top no higher than Z=6.0 mm. The case cavity ceiling is planned at Z=6.5 mm, with the original sloped roof retained above it. Its central 16 mm span has at least 1.25 mm of roof; the edges follow the original key-opening contours. No shoulders project into the adjacent keycap footprints. With each key half shifted 2 mm outward, the nominal CS cap envelopes have at least 2.16 mm of horizontal clearance from the conservative 18 × 33 mm controller envelope; this remains a CAD check using the stated cap and module dimensions. These are controlled assembly targets, not measured fit of the purchased module. Row centers are 15.24 mm apart; pitch along each row is 2.54 mm. At nominal U2 placement `(150,80)` with USB facing negative Y, pad centers are X=142.38 and 157.62, and Y=66.03 through 93.97. Its F.Fab board outline is 17.78 × 30.48 mm, with a provisional USB protrusion to Y=62.22. This outline comes from the open hardware Pro Micro-compatible reference and the official pinout image, **not a vendor dimensioned nice!nano v2 mechanical drawing**; confirm the purchased module, USB shell, pin-post assembly height, and antenna clearance on a physical assembly. A conservative host-copper antenna keepout is X=144–156, Y=86–98, excluding the side pad holes. That keepout is an engineering allowance and not a vendor RF specification.

The symbol and footprints are in project-local `NanoWireless.kicad_sym` and `NanoWireless.pretty`, referenced by project-local library tables. The LED footprint uses the selected V6 datasheet's 1.5 × 1.0 mm lands and pin assignment. KiCad 10 ERC reports **0 errors and 0 warnings**. The exported XML netlist was checked for 36 switches, 36 matrix diodes, the 14 direct matrix connections, battery-switch path, and LED data and power paths. ERC and netlist checks do not establish board routing, 401730 pack safety, RF performance, USB access, or case and pin-post fit.

Short individual soldered posts are the specified assembly for this height-constrained case. Standard low-profile sockets have not been qualified: their above-board height refers to the module-board plane, while the module's overall thickness includes projections on both sides. Any socket assembly must independently meet the complete-envelope limits above. Verify the module low point, USB clearance, and installed height with a real nice!nano v2 and printed case before production.

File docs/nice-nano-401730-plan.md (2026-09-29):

# Endgame nice!nano / 401730 revision requirements

Status: implemented as a complete digital prototype on `codex/nice-nano-401730`, based on XIAO revision `266837a`. See the [prototype handoff](nice-nano-wireless.md) for fabrication files, assembly requirements, and validation. The older wired and XIAO outputs remain separate. Physical hardware has not been tested.

## Accepted choices

- nice!nano **v2**, with the 4-row × 10-column matrix connected directly to GPIOs. Remove the XIAO shift register and its supporting parts.
- Retain all 36 Choc V1/V2 hot-swap switch positions and PCB mounting locations.
- Target the user's generic AliExpress **401730** battery, with direct soldered leads and strain relief, without a JST connector. The earlier preference is 200 mAh or less; the pack's actual capacity, protection, complete dimensions, and charging limit are unverified.
- Enlarge the central PCB opening to **22 × 35 mm**, with a matching case pocket and removable insulating tray. Use an 18.5 × 33 × 5 mm complete-pack planning proxy, not a claimed vendor maximum.
- Keep SW38 at PCB `(150,154)` and retain its case access position. J1 stays at `(148,147.5)` and `(152,147.5)`.
- Keep the original overall case thickness. The finished CAD retains the original sloped roof and maximum height. Internal recesses provide clearance for the specified short-post assembly; the controller hood and side shoulders were removed after a full-height cap-envelope check found interference with adjacent CS keycap envelopes.
- Add a central **Worldsemi WS2812B-V6** 5050 status pixel behind the intact translucent PLA roof. This selected revision supports 3.3 V; older or unidentified WS2812B revisions are not assumed interchangeable.
- Keep the pixel off between brief flashes, including cutting its VCC supply. Leave event/colour meanings unassigned. Provide a compiled, unbound test behavior and API for later work.
- Deliver an independently checked JLCPCB Gerber/drill ZIP, editable PCB/schematic, printable case and tray, and prototype firmware.

## Remaining physical verification

The battery size code does not establish the maximum taped-pack envelope or allowed charge current. Keep the nice!nano charge-boost jumper open; its ordinary setting is nominally 100 mA. The selected pack, controller installation height, USB cable, actual keycap skirts and travel, case print tolerances, charging, radio performance, and LED waveform/rail voltage require first-assembly measurements. A corrected nominal 17.5 × 16.5 mm CS rectangle swept from PCB top through Z=20 clears all 36 key locations in CAD (minimum 0.70 mm); this does not establish physical print fit or larger thumb-cap clearance. The CS MX-stem variant is needed for Choc V2; the linked [Asymplex CS Choc page](https://www.asymplex.xyz/product/cs-chicago-stenographer-profile) describes Choc V1 stems. See the detailed [case](nice-nano-case.md), [electrical](nice-nano-electrical.md), and [firmware](nice-nano-firmware.md) notes.

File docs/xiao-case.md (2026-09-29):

# Endgame XIAO wireless case and battery tray prototype

This is a **new case variant** for the XIAO nRF52840/150 mAh battery PCB. The original `002 CASE/TheENDGAME2024_CASE001.step` is unchanged. Rebuild the deliverables with `python tools/build_xiao_case.py` using `cadquery-ocp` 8.0.1.0.0. The exports are in `002 CASE/XIAO WIRELESS/`: separate STEP and binary STL files for the case and removable battery tray, plus a [mesh preview](../002%20CASE/XIAO%20WIRELESS/case-and-tray-preview.png). These are printable **CAD prototypes**, not a physical fit claim.

The case coordinate frame is `(PCB X − 150, 140 − PCB Y, Z)` in millimetres. The 1.6 mm PCB occupies `Z=0…1.6`; the case is above it. The keyboard's original outside span and all existing switch centres are retained. The new case cuts material where the electronic parts and cable need clearance.

## Implemented geometry

| Feature | Case-frame geometry | Purpose |
| --- | --- | --- |
| Battery pocket | Rounded rectangle `X=−11.1…11.1`, `Y=−4.1…24.1`, R1.0 corners, open from board side to `Z=5.35` | 0.1 mm planar clearance per side beyond the 22 × 28 mm PCB opening and 0.15 mm over the proposed pack top at `Z=5.2` |
| J1 wire channel | `X=−3.4…3.4`, `Y=−11.1…−3.6`, R0.8, open to `Z=3.0` | Two insulated battery leads leave the lower end of the pouch and reach direct-solder J1 pads on F.Cu at PCB `(148,147.5)` and `(152,147.5)`; no JST plug |
| Logic pockets | U3: `X=−4…4`, `Y=32.5…44.8`, to `Z=3.75`; C1/C2: `X=4.5…7.7`, `Y=38…45`, to `Z=3.0`; R1–R3: `X=−8.2…−5.8`, `Y=36.5…45.5`, to `Z=3.0` | F.Cu 74HC595 SOIC-16 and nearby 0603 passives |
| XIAO cavity | `X=−9.5…9.5`, `Y=54.8…77.2`, R1.0, to `Z=6.4` | [Seeed's](https://wiki.seeedstudio.com/XIAO_BLE/) 17.8 × 21 mm non-Sense module centred at PCB `(150,74)`, with 0.6–0.7 mm XY margin; plastic remains above the antenna end |
| USB-C access | `X=−6.4…6.4`, `Y=69.8…82.0`, R0.8, to `Z=7.2` | Opens through the upper exterior edge near case `Y=80.44` for USB insertion toward PCB `−Y` |
| Power switch access | `X=−4.1…4.1`, `Y=−22.3…−12.4`, R0.7, to `Z=4.2` | Front tunnel for PCM12SMTR at PCB `(150,154)`; actuator reaches PCB `Y≈157.15` |
| New heat-set seats | Diameter 4.6 mm × 4.0 mm deep from board top `Z=1.6`, at case `(-9.804941,-14.168516)` and `(9.804965,-14.170142)`; two R4.5 standoffs fill the original 1.2 mm board-to-case gap | Reuse two existing 4 mm PCB holes and fit two additional M3 D4.6 × L3 inserts of the type specified for the original case, preserving the case exterior |
| Battery tray | R1.5 main plate `X=−12…12`, `Y=−5…25`, `Z=−1…0`, with two 1.8 mm-thick screw ears to `Z=−1.8` and D6.2/90° countersinks around 3.3 mm clearance holes | Insulating support under the PCB opening; remove two recessed screws to service the pouch |

The case pocket overlaps the nominal 19.75 × 26.02 × 3.8 mm [Adafruit 1317](https://www.adafruit.com/product/1317) pouch with its long axis front to back. The rounded pocket clears a **hard rectangular nominal-size proxy** at `Z=0.2…5.2`; tapes, lead tabs, and pouch swelling still need a real-pack check. The PCB opening has R1 corners, so its 22 × 28 mm bounding box is a planning envelope rather than an unobstructed sharp-cornered rectangle.

The tray spans the opening and contacts the underside of surrounding PCB laminate. The proposed pouch bottom is at `Z=0.2`, leaving 0.2 mm nominal space above the tray for an insulating/retaining layer. No case solid occupies the opening beneath `Z=0`. The tray reaches `Z=−1.0`, while the case's broad lower perimeter reaches `Z=−1.4`. Without feet, the tray alone is 0.4 mm above the case's nominal desk plane, but the screw heads extend lower.

The original [FDM case parts list](../README.md) specifies four M3 D4.6 × L3 heat-set inserts in 4 mm-deep holes, lists 6 mm countersunk and 5 mm flathead M3 screws, and explains the 5 mm board-only fit through 1.6 mm PCB. Rubber D6.6 grommets or bumpons serve as feet. Boolean probes of the original STEP confirm the **four existing insert bores** at PCB `(54,67.063)`, `(246,67.063)`, `(75.35,144.916)`, and `(224.65,144.916)`. The two central PCB holes used by this tray, `(140.195,154.169)` and `(159.805,154.170)`, have **no original case insert bore**. This variant adds two matching seats beneath those existing PCB holes, without adding PCB holes. It therefore uses **six M3 inserts and six screws total**, while the other ten grommet positions remain available for feet. The new standoffs bring the case underside to the PCB top at `Z=1.6`; the 4 mm insert bores stop at `Z=5.6`, leaving at least **1.0 mm of solid roof** and no raised exterior boss.

Use **two M3 × 6 mm DIN965 90° countersunk screws** for the tray ears, matching the countersunk length already listed in the README. The model seats a head no larger than **6.2 mm diameter × 1.65 mm height** flush with the thickened tray ears at `Z=−1.8`; the resulting threaded engagement in a seated insert is approximately **2.6 mm**, leaving 1.4 mm to the 4 mm bore bottom. Use four or more of the original rubber feet or bumpons with **at least 1.0 mm installed projection below the case's `Z=−1.4` support plane**. This sets the desk plane to at most `Z=−2.4` and leaves **at least 0.6 mm nominal clearance** to the recessed screw heads and ear bottoms. The D6.6 grommet diameter alone does not establish projection; choose or supplement feet to achieve the stated installed height. Check screw seating and avoid overdriving the battery-adjacent inserts.

## Assembly path and access

The electrical design keeps direct battery-wire landing J1 at PCB `(148,147.5)`/`(152,147.5)` and two strain-relief holes at `(148,150.5)`/`(152,150.5)`. Place the protected pouch in the PCB opening, lead exit toward `Y=144`, and route insulated leads in the case channel toward J1. Solder and insulate the leads, secure them through the strain-relief holes, then install the lower tray with M3 × 6 screws through the two existing central board holes into the added heat-set inserts. The centre between the tray ears is clear for the power switch. Removing those screws releases the tray for battery service.

The XIAO's BAT+/GND pads use **two separate short insulated jumpers** from underside board lands near PCB `(146,89)`/`(149,89)` up through the board's access slot near `X=143.7…147.4`, `Y=70.7…74.85`. These wires run on the PCB underside (`Z≤0`), away from this case's F.Cu-side pocket; cover exposed conductor with polyimide insulation and restrain the jumpers to the PCB before case assembly. No long wire tunnel from the pouch to the XIAO is needed. The XIAO case cavity leaves the antenna end of the module beneath nonmetal case material; keep the host copper keepout and avoid metal-filled case material in that region.

## Geometry checks and unresolved fit

The generator verifies that both exported parts are valid single solids, that the case and tray do not overlap, that the nominal pouch, XIAO, USB, U3, and power-switch proxy volumes do not intersect the modified case, and that **at least 1.25 mm of case material** remains above the full enlarged rectangular battery pocket from `Z=5.35` to `Z=6.60`. It also checks the two new heat-set bores, their 1.0 mm local roof, countersunk screw-head seating, and the stated foot clearance. Reimporting the STEP files and checking the binary STLs confirmed valid solids and watertight meshes. All **36 conservative 15 × 15 mm rotated switch-body volumes** have zero intersection with the revised case; the nearest separation remains approximately **1.60 mm**. The tray stays below the PCB and has approximately **4 mm minimum plan clearance** to those switch-body footprints (nearest SW19/SW23), though the assembled hot-swap sockets still need a physical underside check.

The XIAO's 17.8 × 21 mm board outline and the USB connector's approximate **9 × 7.35 mm planar footprint** come from Seeed's [published mechanical resources](https://wiki.seeedstudio.com/XIAO_BLE/) and [v1.2 KiCad board](https://files.seeedstudio.com/wiki/XIAO-BLE/Res/260828_Seeed_Studio_XIAO_nRF52840_v1.2.zip). **Assembled Z heights of the module, USB shell, and cable plug were not verified from a vendor drawing.** The `Z=6.4` module cavity and `Z=7.2` USB passage are prototype allowances, not validated manufacturer clearances. A particular USB plug may need a wider mouth. The recessed power actuator may need a fitted slider extension for finger access. Verify these features with the actual module, plug, switch, assembled PCB, printed case, screws, and battery before calling this a working enclosure.

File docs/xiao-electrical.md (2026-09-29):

# Endgame XIAO nRF52840 electrical revision

This is the editable electrical design for `001 PCB/KICAD/XIAO WIRELESS/TheEndgame2024_XIAO.kicad_sch`. It targets the **standard**, 14-side-pad Seeed XIAO nRF52840, not the Plus or Sense variant. The separate wireless project preserves the 36 existing Choc V1/V2 switch and diode circuits, their UUIDs, and the 4-row × 10-column COL2ROW matrix. The wired RP2040 project remains independent.

## Controller and register

| Host part | Pin(s) | Net and purpose |
| --- | --- | --- |
| U2 XIAO | 1–4 (D0–D3) | `row0`–`row3`, four direct row inputs |
| U2 XIAO | 5–6 (D4–D5) | `col8`–`col9`, direct outputs |
| U2 XIAO | 7–8 (D6–D7) | Unused and marked no-connect |
| U2 XIAO | 9 (D8) | `shift_clk`, U3 pin 11 SRCLK |
| U2 XIAO | 10 (D9) | `latch`, U3 pin 12 RCLK; D9 is the XIAO's MISO-capable pin, but is used as GPIO here |
| U2 XIAO | 11 (D10) | `ser_data`, U3 pin 14 SER |
| U2 XIAO | 12 / 13 | `3V3` output / `gnd` |
| U2 XIAO | 14 VBUS | Unused; USB-C on the module supplies it |
| U2 XIAO | 19 / 20 | `VBAT_SW` / `gnd`, host solder lands for flywires to the module's underside VBAT/GND pads |
| U3 SN74HC595 | 15, 1–7 (QA–QH) | `col0`–`col7` in order |
| U3 SN74HC595 | 13 / 10 | OE held low on `gnd`; SRCLR held high on `3V3` |
| U3 SN74HC595 | 16 / 8 | `3V3` / `gnd`; C1 100 nF and C2 1 µF local bypass |
| U3 SN74HC595 | 9 | QH' unused and marked no-connect |

R1, R2, and R3 are 100 kΩ pulldowns on `shift_clk`, `latch`, and `ser_data`, respectively. They hold the shift-register inputs low while the controller resets. OE is tied low as agreed, so the 595 output register can still contain an undefined value at initial power-up; firmware must shift eight zero bits and latch them before matrix scanning. Firmware also needs to verify row interrupt wake with the selected ZMK driver. Use a 3.3 V compatible **HC** register, such as SN74HC595 in SOIC-16; a 5 V-only HCT variant is inappropriate.

The original buzzer and `Sound` net are deliberately absent. The original polarized buzzer was wired directly to RP2040 GPIO and ground; this revision does not assume the XIAO GPIO can safely drive that acoustic load, and leaving it off saves battery energy. The original SW37 remains the last matrix key. **SW38** is the new battery switch.

## Battery and charging

J1 is the direct-wire protected LiPo landing, with 2.2 mm copper pads and 1.0 mm plated holes at 4.0 mm pitch. Two separate 1.0 mm non-plated holes 3 mm downstream provide lead strain relief. The preferred protected Adafruit 1317 pack is nominally 150 mAh / 3.7 V. Solder its positive lead to J1 pad 1 (`VBAT`, marked B+) and negative lead to J1 pad 2 (`gnd`, marked B−). Do not place solder joints or wire loops where they can press into the pouch.

SW38 is a PCM12-type SPDT slide switch used as an SPST battery disconnect: common pad 2 receives `VBAT`, throw pad 1 carries `VBAT_SW`, and throw pad 3 is unconnected. From U2 host lands 19 and 20, solder **short insulated flying leads** through the access window to the actual underside VBAT and GND pads on the XIAO. Host footprint pads 19/20 are accessible wire lands at board (146,89)/(149,89) when U2 is placed at (150,74); they are *not* in physical contact with the XIAO until those two bridge wires are installed. Verify polarity and continuity before connecting the pack.

Route the two underside jumpers from host lands (146,89) and (149,89) **around the left side of the antenna clearance**. A provisional path is from the lands to an insulated wire corridor near X141–142, Y87, then toward Y76, then into the access window at X143.7–147.4, Y70.7–74.85. Do not take the short straight path through the host antenna exclusion X143–157, Y78.5–85.2. Keep the conductors separate, pre-tin them, solder to the exposed module pads through the aperture, and secure the flat runs to the PCB underside with polyimide tape or a case feature. Check the printed case for wire clearance and strain relief. This is an assembly routing guide; the wires are not PCB copper tracks.

With this positive-lead disconnect, the switch must be **on** to charge the battery by USB. The XIAO's onboard charger remains the only charger in the design. Seeed's current instructions describe approximately 50 mA charging when P0.13 is high-impedance; software must not drive P0.13 low, which selects approximately 100 mA. Measure charge current and verify the exact purchased board revision during prototype bring-up.

## Module footprint and assembly

The local U2 footprint is centered on the standard module's 17.8 × 21.0 mm board. USB-C faces negative PCB Y; at nominal board placement (150,74), the module is X141.1–158.9 and Y63.5–84.5. Its fourteen 2.54 mm-pitch side pads reproduce Seeed's January 2026 `XIAO-nRF52840-SMD` host footprint centers and 2.75 × 2.0 mm solder lands. It intentionally omits hidden underside host pads 15–18 and 21–22. An Edge.Cuts access opening, local X −6.3 to −2.6 and Y −3.3 to +0.85, exposes the two underside battery contacts after the module is mounted. Check that the fabricator routes this enclosed opening and that the remaining castellated joints can be inspected and reworked.

Seeed's August 2026 v1.2 KiCad board locates the antenna chip close to the far end, opposite USB: about 1.1 mm in from that edge and 1.8 mm left of board center. At the nominal host placement, that is approximately (148.2,83.4). The host board should have no copper fill, traces, or vias under a conservative antenna region X143–157, Y78.5–85.2 on both copper layers, while side castellated pads and their outward escapes remain available. This rectangle is a design margin derived from the module drawing; Seeed does not specify it as an RF clearance dimension. Keep the battery pouch and metal parts away from the antenna. Confirm RF performance on the assembled prototype.

## Digital validation and sources

The digital electrical prototype is complete. The KiCad 10.0.6 schematic ERC reports **0 errors and 0 warnings**. The routed PCB passes full KiCad 10 DRC with **0 violations, 0 unconnected items, and 0 schematic-parity violations**. The exported XML netlist was checked for all 36 switches, all 36 diodes, all 14 matrix nets, and the allocation above. See the [DRC report](validation/xiao-pcb/drc.json) and [geometry/parity report](validation/xiao-pcb/geometry.json).

The board is designed for **2 layers, 1.6 mm FR-4**. The exported outline measures **219.000032 × 96.106071 mm**, giving order dimensions of **219 × 96.11 mm**. The internal openings are **22 × 28 mm** for the battery and **3.7 × 4.15 mm** for access to the XIAO underside battery pads. The [wireless Gerber/drill ZIP](../001%20PCB/GERBER/XIAO%20WIRELESS/TheEndgame2024_XIAO_Choc_V1_V2_JLCPCB.zip) has been independently validated: seven graphic layers, 215 plated drills, 148 non-plated holes/slots, all drill positions match the source within 0.002 mm, and three closed outline contours. Its SHA-256 is `21442495bcce91add5d830b43f0e740c89e97c63afcf3fc9f35ef46fb2c5e6da`. The validation report is [gerbers.json](validation/xiao-pcb/gerbers.json). No JLCPCB upload or portal preview has been performed. Digital ERC/DRC and Gerber checks do not verify a physical assembly: charge current, battery sensing against a meter, RF range, USB/cable fit, wire clearance, and actual mechanical fit remain untested.

Primary references: [Seeed XIAO nRF52840 guide and charging behavior](https://wiki.seeedstudio.com/XIAO_BLE/), [Seeed XIAO KiCad footprint library](https://files.seeedstudio.com/wiki/XIAO-KiCad-Library/New_XIAO_Series_Footprints.zip), [Seeed underside pad drawing](https://files.seeedstudio.com/wiki/XIAO-BLE/Bottom-pad-positioning.zip), [Seeed v1.2 KiCad board](https://files.seeedstudio.com/wiki/XIAO-BLE/Res/260828_Seeed_Studio_XIAO_nRF52840_v1.2.zip), [TI SN74HC595 datasheet](https://www.ti.com/lit/ds/symlink/sn74hc595.pdf), and [Adafruit protected 150 mAh cell](https://www.adafruit.com/product/1317).

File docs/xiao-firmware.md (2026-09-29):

# XIAO wireless firmware

This directory contains the Endgame ZMK shield for the proposed standard Seeed XIAO nRF52840 wireless revision. It preserves the original 4-row × 10-column COL2ROW matrix and 36-key physical layout. The existing RP2040/QMK images and configuration remain for the wired board.

## Pin allocation

| XIAO pin | Use |
| --- | --- |
| D0–D3 | Matrix rows 0–3, direct active-high inputs with pull-downs |
| D4–D5 | Matrix columns 8–9, direct active-high outputs |
| D8 | 74HC595 serial clock / SPI SCK |
| D9 | 74HC595 storage-register clock / SPI chip select |
| D10 | 74HC595 serial data / SPI MOSI |
| 74HC595 QA–QH | Matrix columns 0–7, in that order |
| P0.13 | Charger current select, high-impedance input for the approximately 50 mA setting |
| D6–D7 | Reserved |

The shield uses the board's `xiao_spi` and `xiao_d` aliases. The 595 is configured as the eight-output GPIO provider described in the [ZMK shift-register guide](https://zmk.dev/docs/hardware-integration/shift-registers). With OE tied to GND and SRCLR tied to 3V3 as specified in the hardware plan, outputs are enabled continuously and firmware initializes them low as part of matrix setup. The 595 outputs must connect QA through QH to columns 0 through 7 in the listed order. Keep the row inputs directly connected to the MCU so a row transition can wake scanning.

## Keymap behavior

The base layer preserves the source QWERTY layout and both outer Shift keys. Holding the left inner thumb enters the number/symbol layer while tapping it sends Escape; holding the right inner thumb enters the navigation/editing layer while tapping it sends Delete. The raise layer also selects Bluetooth slots 0–2, advances to the next slot, and clears the active bond. Battery level reporting uses ZMK's XIAO BLE board sensor and the standard BLE Battery Service.

ZMK's upstream XIAO board definition provides a voltage-divider sensor on ADC channel 7, controlled by P0.14; the charger-current GPIO hog in this shield configures P0.13 as an unpulled input, which Seeed documents as the lower-current charge setting. The firmware build proves these definitions are accepted by the pinned ZMK/Zephyr source. Confirm the sensing path and charge current on the exact production XIAO revision with a meter before relying on its reported percentage or charging behavior; firmware configuration does not replace those hardware checks. See the [XIAO nRF52840 hardware documentation](https://wiki.seeedstudio.com/XIAO_BLE/) and ZMK's [battery configuration guide](https://zmk.dev/docs/hardware-integration/battery).

## Shift-register interrupt fix

The selected upstream revision still has the behavior reported in [ZMK issue #2945](https://github.com/zmkfirmware/zmk/issues/2945): the [GPIO matrix interrupt callback](https://github.com/zmkfirmware/zmk/blob/5b51501fead672c41b5cfb396f3dafe0894bf4e9/app/module/drivers/kscan/kscan_gpio_matrix.c) disables row interrupts and writes every output low immediately, while the [595 GPIO driver](https://github.com/zmkfirmware/zmk/blob/5b51501fead672c41b5cfb396f3dafe0894bf4e9/app/module/drivers/gpio/gpio_595.c) returns `-EWOULDBLOCK` for SPI writes from interrupt context. The bundled patch changes the callback to disable only the direct row interrupts, then reset 595-backed columns in the matrix workqueue before scanning. This preserves interrupt wake-up and avoids SPI transactions in the GPIO ISR. `patches/zmk-kscan-spi-irq.patch` is applied by the build script to the exact pinned source revision.

The keyboard uses the GPIO matrix driver's normal interrupt mode, not polling. In idle, all columns are high so a pressed key raises a directly connected row; the GPIO ISR masks row interrupts and schedules the scan worker. The worker sets columns low, scans one column at a time, and restores the all-high wake state after debounce completes. SPI errors retry with bounded backoff, then attempt to restore row wake interrupts; a persistent error is retried at one-second intervals without a tight loop or repeated log flood. Errors from the final all-high wake transition are propagated into this recovery path. ZMK deep sleep is enabled with its 15-minute default idle-sleep timeout. First-board testing must verify row wake from actual system-off/deep sleep as well as ordinary idle scans.

## Reproducible build

The manifest pins ZMK to commit `5b51501fead672c41b5cfb396f3dafe0894bf4e9` (2026-09-28 upstream main snapshot) and imports that revision's pinned Zephyr and module revisions. Install the [ZMK local build prerequisites](https://zmk.dev/docs/development/local-toolchain/installation), including `west`, CMake, Ninja, the Zephyr SDK and device-tree compiler. From the repository root, run:

```sh
cd '003 FIRMWARE/zmk-endgame'
./build.sh
```

The script initializes and updates the West workspace, applies the ISR-safe scan patch, builds board `xiao_ble/nrf52840/zmk` with shield `endgame`, enables sleep, and copies the UF2 to `firmware/endgame-xiao-nrf52840.uf2`. To enter the bootloader, double-tap the XIAO reset button and copy the UF2 to the mounted XIAO BLE volume, as described in the [Zephyr XIAO BLE board guide](https://docs.zephyrproject.org/latest/boards/seeed/xiao_ble/doc/index.html).

No hardware test has been performed. Before treating this branch as a working wireless keyboard, check all 36 switches, rollover, Bluetooth pairing and slot changes, battery reporting against a meter, approximately 50 mA charging, wake from both idle and deep sleep, and idle current on the assembled board.

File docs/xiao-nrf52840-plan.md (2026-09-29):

# Endgame XIAO nRF52840 development branch

Status: historical design study, superseded by the [implemented wireless prototype](xiao-wireless.md). Dimensions and pending-work statements below describe the preliminary study; use the current PCB, case, and assembly notes for fabrication.

The `codex/xiao-nrf52840-battery` branch starts from Choc V1/V2 commit `503635fe0c49a6c597ee685ef395d58eaf00e6dd`. It targets the standard Seeed Studio XIAO nRF52840, a central battery opening, and a modified case. The previous wired RP2040 Gerbers remain the last completed manufacturing release; they do not implement this controller or battery opening.

## Agreed constraints

- Retain all 36 switch positions and Choc V1/V2 hot-swap support.
- Case changes around the battery and USB port are allowed.
- Use a thin rechargeable battery with nominal capacity **200 mAh or less**.
- Solder battery leads directly to labeled B+/B− PCB pads; no JST connector footprint.
- Preserve the existing perimeter and mounting points where possible; the new internal cutout is an intentional change.
- Use lower-cost agents for sourcing and bounded CAD analysis.

## Battery target

The preferred obtainable part is the **Adafruit 1317 protected 150 mAh, 3.7 V LiPo**, listed at **19.75 × 26.02 × 3.8 mm**. Reserve a preliminary **22 × 28 mm** battery envelope and **5 mm** of vertical space, plus a lead channel and strain relief. Those allowances are design assumptions, not a vendor maximum-size or lifetime expansion specification. The final pocket must not press against the pouch. The supplied JST-PH plug is not part of the design: the insulated battery leads terminate directly at clearly marked **B+ and B− solder pads** on the PCB. Preserve the pack's protection circuit.

The thinner alternative is a **LiPol LP302030, 130 mAh**, with protected-pack dimensions **20 × 31 × 3.0 ±0.3 mm**, but one-off Canadian sourcing is less attractive. See [battery sources, pricing, and charge specifications](xiao-battery-options.md).

Use the XIAO's low approximately **50 mA** charge setting. Verify the exact board revision's charger configuration and measure the charge current on the first assembled prototype. Connect the protected pack through the PCB's B+/B− pads to the XIAO battery pads, with a small physical disconnect switch in the positive lead. With this simple switched-battery circuit, the switch must be on for USB charging. Place the solder joints beside the pouch, where they cannot press into it, and provide wire strain relief. This is a proposed power circuit; none of it exists in the released RP2040 PCB.

## Controller and matrix

The current schematic and QMK configuration agree on a **4-row × 10-column COL2ROW matrix**, requiring 14 signals. The standard XIAO exposes 11 main GPIOs. It is not a pin-compatible substitute for the existing RP2040 Zero.

The preferred starting architecture preserves the existing matrix and uses **one 74HC595 serial output register for eight columns**, two direct GPIO columns, and four direct GPIO row inputs. This consumes **nine XIAO GPIOs**: three for the register plus two columns and four rows. Two pins remain available. Keeping row inputs on the MCU permits interrupt-based key wake-up. ZMK documents this output-expansion approach; its regular matrix driver accepts GPIO references per row/column.

Proposed allocation, subject to routing and firmware validation:

| XIAO pin | Proposed function |
| --- | --- |
| D0–D3 | row0–row3 inputs |
| D4–D5 | col8–col9 outputs |
| D8 | Register shift clock / SPI SCK |
| D9 | Register latch clock / SPI chip-select; not MISO |
| D10 | Register serial data / SPI MOSI |
| D6–D7 | Reserved until buzzer/power-control decisions are finalized |
| 3V3 / GND | Register supply, local decoupling, and logic reference |

The register's QA–QH outputs supply col0–col7. Do not use a 5 V-only HCT device in place of a suitable 3.3 V HC part. Final design must establish output-enable/reset behavior during power-up, avoid floating inputs, and verify both normal scanning and interrupt wake-up on the selected ZMK revision. The current RP2040 QMK/Vial firmware cannot be flashed onto the XIAO; a ZMK shield, matrix transform, and keymap are required.

## Mechanical integration to resolve

The existing controller is at PCB coordinates approximately (150, 72.871) mm. Keep the replacement near the center USB opening, checking the XIAO body, soldering access, USB connector height, antenna copper keepout, and battery-pad access from the actual module drawing. Do not place the battery or a metal holder over its antenna.

The existing bottom-side buzzer is at (150, 105) mm. The battery study must account for its pads and body, the two lower center grommet features, switch sockets and locating slots, and copper crossing the proposed cutout. An apparently blank area of solder mask is not necessarily free of copper or case material.

The first measured candidate is a **22 × 28 mm** opening centered at **PCB (150, 130) mm**, spanning **X=139–161, Y=116–144 mm**. It clears the conservative rotated 15 × 15 mm switch bodies by approximately **6.61 mm**, the existing buzzer courtyard by **3.05 mm**, and the lower center mount envelopes (assumed 5 mm radius) by approximately **5.17 mm**. No existing discrete track, via, or pad crosses this rectangle. The existing ground fill does, so the zone must be refilled after adding an actual Edge.Cuts opening.

The selected vertical arrangement places the battery through the PCB plane: its preliminary 5 mm envelope spans **Z=0.2–5.2 mm**, where the PCB occupies Z=0–1.6 mm. Removing the intersecting 3.6 mm of case material leaves **at least 1.50 mm of nominal roof** across the full rectangle. A raised top cover is therefore not required by this nominal arrangement. The pocket's final printing clearance and depth must be checked again because either can reduce that roof thickness. See the [measured fit study](validation/xiao-battery-fit.md) and [plan-view diagram](validation/xiao-battery-fit.svg). No cutout or case modification has yet been applied.

An opening alone does not retain or insulate a pouch cell. The modified case needs an insulating, load-bearing bottom tray beneath the PCB opening, a smooth pocket, lead strain relief, and access to the battery disconnect. Verify the tray's desk clearance and fasteners in the revised assembly. Keep the external footprint compact and avoid weakening the narrow ligaments that support the switch halves.

## Completion checks before generating new Gerbers

1. Select the battery pocket and verify its full pack, solder-pad, wire, and case envelope.
2. Implement and match the controller, register, and power circuit in the schematic and PCB.
3. Route around the cutout, refill zones, run ERC/DRC, and verify all 36 keys against the firmware matrix.
4. Build ZMK for the actual XIAO revision and test register initialization, every key, wake-up, battery sensing, and charge-current configuration.
5. Export updated case CAD and inspect controller, socket, battery, cable, and switch fit in assembly.
6. Generate a distinctly named wireless Gerber/drill ZIP and independently check the internal cutout and all V1/V2 drills. The existing wired ZIP must remain identifiable.

## Primary references

- [Seeed XIAO nRF52840 hardware and charging documentation](https://wiki.seeedstudio.com/XIAO_BLE/).
- [ZMK shift-register integration](https://zmk.dev/docs/hardware-integration/shift-registers).
- [ZMK matrix driver configuration](https://zmk.dev/docs/config/kscan).
- [TI SN74HC595 datasheet](https://www.ti.com/lit/ds/symlink/sn74hc595.pdf).
- [Adafruit 1317 dimensions and protection](https://www.adafruit.com/product/1317).

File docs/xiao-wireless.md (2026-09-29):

# Endgame XIAO wireless prototype handoff

This branch contains a completed **digital wireless prototype** for the Endgame using the standard Seeed XIAO nRF52840 and a protected central LiPo cell. The schematic/ERC, routed PCB/KiCad 10 DRC, case and battery-tray CAD, ZMK firmware build, and Gerber/drill export are complete. The fabrication package was checked independently, but it has not been uploaded to the JLCPCB portal or previewed there. No physical wireless PCB/case assembly, battery charging, RF performance, or USB/cable fit has been tested. The older wired RP2040 Gerber ZIP is not for this design.

The original 36 Choc switch positions, diode circuits, 4-row × 10-column COL2ROW matrix, and Choc V1/V2 hot-swap compatibility are retained. The buzzer was removed from the wireless revision. The wired RP2040 design and its existing manufacturing files remain independent.

## Prototype status

| Area | Current state | Handoff |
| --- | --- | --- |
| Electrical design | Schematic/ERC and routed board/KiCad 10 DRC are complete. The Gerber/drill package is independently validated; JLCPCB upload and portal preview have not been performed. | [Electrical design notes](xiao-electrical.md), [schematic](../001%20PCB/KICAD/XIAO%20WIRELESS/TheEndgame2024_XIAO.kicad_sch), [PCB layout](../001%20PCB/KICAD/XIAO%20WIRELESS/TheEndgame2024_XIAO.kicad_pcb), [wireless Gerber ZIP](../001%20PCB/GERBER/XIAO%20WIRELESS/TheEndgame2024_XIAO_Choc_V1_V2_JLCPCB.zip), [Gerber front preview](../001%20PCB/GERBER/XIAO%20WIRELESS/front-preview.png), [KiCad DRC report](validation/xiao-pcb/drc.json), [geometry report](validation/xiao-pcb/geometry.json), [Gerber inspection report](validation/xiao-pcb/gerbers.json) |
| Case and tray | Printable CAD files and mesh checks are complete, but physical fit against the board, cell, and USB cable is untested. | [Case prototype notes](xiao-case.md), [case STL](../002%20CASE/XIAO%20WIRELESS/TheENDGAME2024_XIAO_CASE.stl), [battery tray STL](../002%20CASE/XIAO%20WIRELESS/TheENDGAME2024_XIAO_BATTERY_TRAY.stl), [case STEP](../002%20CASE/XIAO%20WIRELESS/TheENDGAME2024_XIAO_CASE.step), [battery tray STEP](../002%20CASE/XIAO%20WIRELESS/TheENDGAME2024_XIAO_BATTERY_TRAY.step) |
| Firmware | Pinned ZMK config and locally built UF2 are ready for prototype bring-up; firmware behavior and matrix wake need assembled-board tests. | [Firmware notes](xiao-firmware.md), [build configuration](../003%20FIRMWARE/zmk-endgame/), [prototype UF2](../003%20FIRMWARE/zmk-endgame/firmware/endgame-xiao-nrf52840.uf2) |
| Assembly and battery | Direct-wire 150 mAh protected cell, switched battery path, and XIAO underside jumpers are specified. Charge current, sensing, battery safety, RF behavior, USB/cable access, and assembled mechanical fit have not been tested. | [Battery options](xiao-battery-options.md), [electrical assembly details](xiao-electrical.md#battery-and-charging) |

KiCad 10 ERC and DRC both report zero violations; the DRC report also records zero unconnected items and zero schematic-parity violations. The board uses a 2-layer, 1.6 mm FR-4 stackup. The final Gerber outline measures 219.000032 × 96.106071 mm, so order dimensions are **219 × 96.11 mm**. The internal battery opening is 22 × 28 mm and the XIAO underside-pad access opening is 3.7 × 4.15 mm. The [geometry report](validation/xiao-pcb/geometry.json) records these openings and retained switch/diode counts. The [Gerber report](validation/xiao-pcb/gerbers.json) records seven graphic layers, 215 plated drills, 148 non-plated holes/slots, all drill positions registered to the PCB within 0.002 mm, and three closed outline contours. The archive SHA-256 is `21442495bcce91add5d830b43f0e740c89e97c63afcf3fc9f35ef46fb2c5e6da`. Physical hardware build, charge current, RF performance, and USB/cable fit remain untested.

## Wireless-specific component BOM

This is the prototype BOM for a complete 36-key assembly. Existing keyboard parts are listed because the wireless PCB retains their positions and circuitry.

| Qty | Part | Notes |
| ---: | --- | --- |
| 1 | Standard Seeed XIAO nRF52840 | Use the non-Plus, non-Sense module; D0–D3 are rows, D4–D5 direct columns, D8/D9/D10 drive the register. |
| 1 | SN74HC595, SOIC-16 | 3.3 V HC logic, not a 5 V-only HCT variant; QA–QH drive matrix columns 0–7. Tie OE to GND and SRCLR to 3V3. |
| 1 each | 100 nF and 1 µF, 0603 capacitors | Local 74HC595 bypass capacitors. |
| 3 | 100 kΩ, 0603 resistors | Pulldowns on shift clock, latch, and serial data. |
| 1 | PCM12SMTR SPDT slide switch | Used as the positive battery disconnect; third contact is unused. |
| 1 | Adafruit 1317 protected LiPo, 3.7 V, nominal 150 mAh | Use the protected cell. Remove/omit its JST-PH plug and solder the two leads directly to the PCB's labeled B+/B− pads. There is no JST battery connector in this design. |
| 2 | Short insulated jumper wires | Connect host-side PCB lands to the XIAO's underside BAT and GND pads. Route both around the **left side** of the antenna keepout through the access opening; they are hand-soldered wires, not PCB copper tracks. |
| 36 | Choc V1 or V2 switches | Original physical switch positions and hot-swap geometry are retained. |
| 36 | Choc hot-swap sockets | Existing hot-swap design; do not substitute a direct-solder-only footprint. |
| 36 | 1N4148W SOD-123 diodes | One diode per existing matrix switch circuit. |
| 6 | M3 D4.6 × 3 mm heat-set inserts and six M3 case screws | Four existing case mounts plus two new battery-tray mounts. Use two M3 × 6 mm 90° countersunk screws for the tray ears; use the original four case-mount screws for the remaining points. |
| 4 or more | Rubber feet or bumpons | Choose enough installed height to clear the tray-ear screw heads; case notes specify at least 1 mm projection below its support plane. |

There is **no buzzer** in the wireless BOM. Keep the cell's protection circuit; do not compress, puncture, or trap the pouch or its leads.

## Battery and jumper assembly

Solder the protected cell directly to B+ and B−, observing polarity, and use the switch in the positive lead. The supplied Adafruit connector is not used. If removing it, cut and insulate one lead before cutting the other so the live battery leads cannot short together. Secure the leads through the PCB strain-relief holes and route them through the case channel without pressure against the cell.

The slide switch must be **ON while charging over USB** so the XIAO's onboard charger remains connected to the cell. The intended XIAO charger setting is its low, approximately **50 mA** selection: leave P0.13 as an unpulled, high-impedance input. Confirm the exact XIAO board revision and measure charge current on the first assembled board.

Connect the PCB host lands to the module's underside VBAT and GND pads with two short insulated flywires through the access slot. Route them around the left of the antenna clearance; do not cross the antenna keepout or substitute a straight route through it. Secure and insulate the wires on the PCB underside before closing the case. See the [electrical routing dimensions](xiao-electrical.md#battery-and-charging) and [case wire-clearance notes](xiao-case.md#assembly-path-and-access).

## Prototype bring-up gates

Before calling this a working wireless keyboard, review the Gerber package in the fabricator's portal and physically verify switch fit, both XIAO jumpers, USB/cable access, tray and pack fit, and strain relief. On the assembled board, test all 36 keys and rollover, Bluetooth pairing and slot changes, battery reporting against a meter, the approximately 50 mA charge setting with the switch on, idle current, and wake from both ordinary idle and deep sleep. Record measured results before treating the design as a proven hardware build.

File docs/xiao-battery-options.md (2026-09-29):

# Thin protected LiPo options for XIAO nRF52840

**Recommendation: Adafruit 1317, 150 mAh, remains the practical one-off candidate in Canada, subject to confirming current stock.** PiShop.ca lists it at CA$7.95, and Adafruit publishes the complete pack dimensions and a 127.5 mm lead. Its supplied JST-PH plug will not be used: remove it and solder the leads directly to the PCB's labeled battery pads. Budget around **4.5–5 mm** for the pack area to allow room above its listed 3.8 mm thickness for dimensional variation, surface tape, and avoiding compression; the vendor does not publish a dimensional tolerance. Provide a wire channel and strain relief so the lead exit is not pinched or pulled.

If every fraction of a millimetre matters and a custom bare-wire connection is acceptable, LiPol LP302030 is thinner: **3.0 ±0.3 mm** overall including its protection circuit. Its official order flow is sample/contact based and lists **US$99 economy / US$199 express shipping to Canada**, so it is a poor one-off purchase. No readily purchasable Canadian stock listing surfaced in this check.

| Pack | Published pack dimensions | Protection / wiring | Charge specification | One-off sourcing |
|---|---|---|---|---|
| [Adafruit 1317](https://www.adafruit.com/product/1317) | 19.75 × 26.02 × 3.8 mm; 127.5 mm lead. Listing gives no dimensional tolerance. | Protection for overcharge, over-discharge, and short circuit. Supplied genuine 2-pin JST-PH plug is removed for direct wire soldering; check lead polarity before soldering. | Adafruit says charge at **150 mA or less**; its linked cell datasheet specifies 4.2 V CV, 30 mA standard charge and 150 mA quick-charge current. XIAO low setting (~50 mA CC) is within the product limit and below its quick-charge limit. | [PiShop.ca listing](https://www.pishop.ca/product/lithium-ion-polymer-battery-3-7v-150mah/): CA$7.95; availability needs checking. [Adafruit direct](https://www.adafruit.com/product/1317): US$5.95, shown in stock on its product page; ships internationally, with lithium shipping limits. [DigiKey listing](https://www.digikey.ca/en/products/detail/adafruit-industries-llc/1317/5054547) is another established supplier; inventory/price may vary by Canadian destination. |
| [LiPol LP302030](https://www.lipolbattery.com/Lithium-Ion-Polymer-Battery-LP302030.html) | 31 × 20 × 3.0 mm; datasheet drawing gives ±0.3 mm thickness tolerance. Includes PCM. | Protection circuit included, no NTC, two 50 mm AWG28 bare wires. | Datasheet: 4.2 V ±50 mV maximum charge voltage; 65 mA standard / 130 mA maximum charge current; charge temperature +10 to +45 °C. XIAO’s ~50 mA setting is below the 65 mA standard current and is suitable. | [Manufacturer product/order page](https://www.lipolbattery.com/Lithium-Ion-Polymer-Battery-LP302030.html) says samples require contacting them; for Canada it lists US$99 economy or US$199 express shipping and warns import clearance may apply. No fixed single-unit price or Canadian stock was posted. |

## XIAO charging and integration notes

Seeed’s [XIAO nRF52840 wiki](https://wiki.seeedstudio.com/XIAO_BLE/#battery-charging-current) documents selectable charging current of about **50 mA or 100 mA** during the constant-current phase; current tapers near full charge. For these small cells, use the low (~50 mA) setting. The Adafruit cell’s manufacturer datasheet gives 150 mAh nominal and 142 mAh minimum capacity, so the initial charge rate is about 0.33C nominal (0.35C at minimum capacity). LiPol’s 130 mAh minimum capacity gives about 0.38C, under its 0.5C standard-charge rating.

For direct soldering, Adafruit's JST-PH plug is unused: remove it by cutting one conductor at a time, insulating each cut end, then solder the positive and negative leads to the PCB's labeled BAT+ and BAT− pads after confirming polarity. Do not let the stripped leads touch each other. Add strain relief and route the wires through a channel with enough slack that case assembly cannot pinch or tug them. The protection circuit is useful fault protection, but it is not a substitute for the board's correctly configured single-cell CC/CV charger. Avoid physically squeezing or puncturing the pouch.

## Sources

- [Adafruit 1317 product page](https://www.adafruit.com/product/1317) and linked [402025 150 mAh cell-with-PCM datasheet](https://cdn-shop.adafruit.com/product-files/1317/C1515_-_Li-Polymer_402025_150mAh_3.7V_with_PCM.pdf).
- [PiShop.ca Adafruit 1317 listing](https://www.pishop.ca/product/lithium-ion-polymer-battery-3-7v-150mah/).
- [LiPol LP302030 product page](https://www.lipolbattery.com/Lithium-Ion-Polymer-Battery-LP302030.html) and [LP302030 datasheet](https://www.lipolbattery.com/LiPo-Battery-Datahseet/LiPo-Battery-LP302030.pdf).
- [Seeed XIAO nRF52840 wiki](https://wiki.seeedstudio.com/XIAO_BLE/#battery-charging-current).

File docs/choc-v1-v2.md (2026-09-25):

# Endgame Choc V1/V2 revision

This fork adds Kailh Choc V2 (PG1353) hot-swap support while retaining Choc V1 hot-swap support and the original Endgame case geometry. It targets the supplied **CPG135301D02** drawing. It does not change the key matrix or firmware.

## Mechanical changes

All 36 switch positions in both the SILKSCREEN and COPPER PCB variants receive:

- A **5.00 mm non-plated center hole**, replacing the 3.40 mm hole.
- A **1.50 × 2.00 mm non-plated relief slot**, oriented with the switch and located according to the manufacturer drawing.
- Both original **1.70 mm Choc V1 locating holes** retained at ±5.50 mm.
- The existing hot-swap socket pads and electrical pin positions retained.

The V2 relief slot overlaps an optional direct-solder pad in the upstream HSxSolder footprint. This revision replaces that auxiliary pad with a **0.60 mm routing land / 0.30 mm plated hole**, moves it 0.30 mm, and reconnects the traces. The original direct-solder option is no longer supported; **use Choc hot-swap sockets with either switch family**. The remaining auxiliary holes are part of the routing, not an alternative switch pattern.

The new `SW_choc_v1_v2_HS_1u` and `SW_choc_v1_v2_HS_1.5u` footprints are stored in the project library and assigned in both schematics. The upstream V1 footprints remain available for reference.

## Existing case and keycaps

The PCB perimeter, cutouts, four screw mounting holes, other mounting features, component locations, all switch centers/angles, and **1.6 mm board thickness** are preserved. Do not change the thickness when ordering a replacement PCB.

The included `002 CASE/TheENDGAME2024_CASE001.step` was registered to the PCB using its four mounting holes: case coordinates are `(PCB X - 150, 140 - PCB Y)`. A conservative 15 × 15 mm switch-body envelope from Z=1.6 to 8.0 mm at each switch position has zero intersection with the case. The minimum computed separation is approximately **1.60 mm**. This is a CAD clearance check, not a physical prototype test; it does not assess printing tolerances, switch retention, or the keycaps' moving envelope.

The original alpha spacing is approximately **18 × 17 mm**. Choc V2 uses an MX-style stem, but that does not make every MX keycap suitable for this spacing. Select caps with skirts and thumb-key dimensions that clear neighbouring keys and the original case. Choc V1 MBK caps do not fit the V2 stem. The old library's external V1/MBK 3D-model paths are not a V2 assembly model.

## Sources

- [Upstream Endgame](https://github.com/OldMan6955/TheEndgame2024), starting commit `b66038b`.
- [Kailh CPG135301D02 drawing supplied for this conversion](https://cdn.shopify.com/s/files/1/0657/6075/5954/files/SPEC-CPG135301D02_Kailh_Choc_V2_Low_Profile_Brown_Switch.pdf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), revision A, 2020-04-15. The PCB recommendation uses a relief slot; an older PG1353 drawing with a circular relief hole was not used for the final geometry.
- [JLCPCB KiCad Gerber/drill instructions](https://jlcpcb.com/help/article/how-to-generate-gerber-and-drill-files-in-kicad-9).

The original CERN-OHL-S-2.0 license and upstream attribution continue to apply. Modified 2026-09-25 for the Choc V1/V2 fork.

## Source checks

Run `python3 tools/verify_choc_compatibility.py` to verify all switch holes and compare the board's mechanical interfaces with the recorded upstream commit. This check does not replace KiCad DRC. The final manufacturing export must use refilled copper zones and the unchanged 1.6 mm stackup.

## Manufacturing download and order settings

Use **[TheEndgame2024_Choc_V1_V2_JLCPCB.zip](../001%20PCB/GERBER/CHOC%20V1%20V2/TheEndgame2024_Choc_V1_V2_JLCPCB.zip)**. This is the updated SILKSCREEN variant. The older `SILKSCREEN GERBER` and `COPPER GERBER` folders are upstream V1-only archives and are not the output of this conversion.

The new ZIP contains seven RS-274X Gerber layers (front/back copper, front/back mask, front/back silkscreen, and outline), separate metric Excellon PTH and NPTH drill files, and a Gerber job file. Drill slots use G85. No assembly order or stencil is included.

| JLCPCB option | Setting |
| --- | --- |
| Material | FR-4 |
| Copper layers | 2 |
| Thickness | **1.6 mm** |
| Outer copper | 1 oz |
| Board size | Approximately 219 × 96.1 mm; use the outline in the ZIP |
| Solder mask / silkscreen | Your preference; preview colors are illustrative |
| Surface finish | HASL or ENIG as preferred |
| Assembly | Bare PCB; solder components and Choc sockets separately |

The slot tooling is 1.5 mm wide with 0.5 mm centerline travel, producing a 1.5 × 2.0 mm slot. Confirm that the manufacturer's preview recognises all 36 slots and 36 large center holes. The PCB is a new, **physically untested** revision; prototype fit and keycap clearance have not been verified on assembled hardware.

## Validation record

- KiCad **10.0.6**: zero errors, zero warnings, zero unconnected items for both variants, using the upstream rule settings. No DRC rules were relaxed or exclusions added. The silkscreen board also passes schematic parity.
- Project-local footprint tables resolve the upstream library configuration warnings.
- All 36 switch centers and rotations, the board outline/cutouts, thickness, and every non-switch footprint remain identical to upstream. Firmware is unchanged.
- 17 trace sections were rerouted and eight 0.60/0.30 mm vias were added. One upper bus segment uses 0.20 mm trace width; other rerouted segments retain 0.25 mm. The final routing was checked by KiCad; no Freerouting session was imported into the released board.
- Copper zones were refilled. The large PCB text diff is predominantly regenerated fill polygons; the source remains in the original KiCad 8 file format.
- Independent Gerbonara **1.6.3** parsing of the ZIP verifies seven graphic layers, **181 plated holes**, and **144 non-plated holes/slots**. All 36 sets of new/retained switch drills are registered against the source within the 0.002 mm check tolerance, including rotated slots.
- Top/bottom previews were rendered from the exported Gerbers and drill data and inspected. They show illustrative green solder mask and gold pads, not an order selection.
- The case check uses OpenCascade through `cadquery-ocp 8.0.1.0.0`; 36 conservative switch envelopes clear the supplied case model, minimum separation approximately 1.60 mm.

Machine-readable reports and source/archive hashes are in [validation](validation/). Optional reproducibility commands:

```sh
python3 tools/verify_choc_compatibility.py
# Requires cadquery-ocp:
python3 tools/check_case_fit.py --output docs/validation/case-fit.json
# Requires gerbonara:
python3 tools/verify_gerbers.py
# Requires kicad-cli; choose a new directory:
python3 tools/export_jlcpcb.py --output /tmp/endgame-export
```

The standalone PDF linked above is the dimensional source; it is not redistributed in this repository.

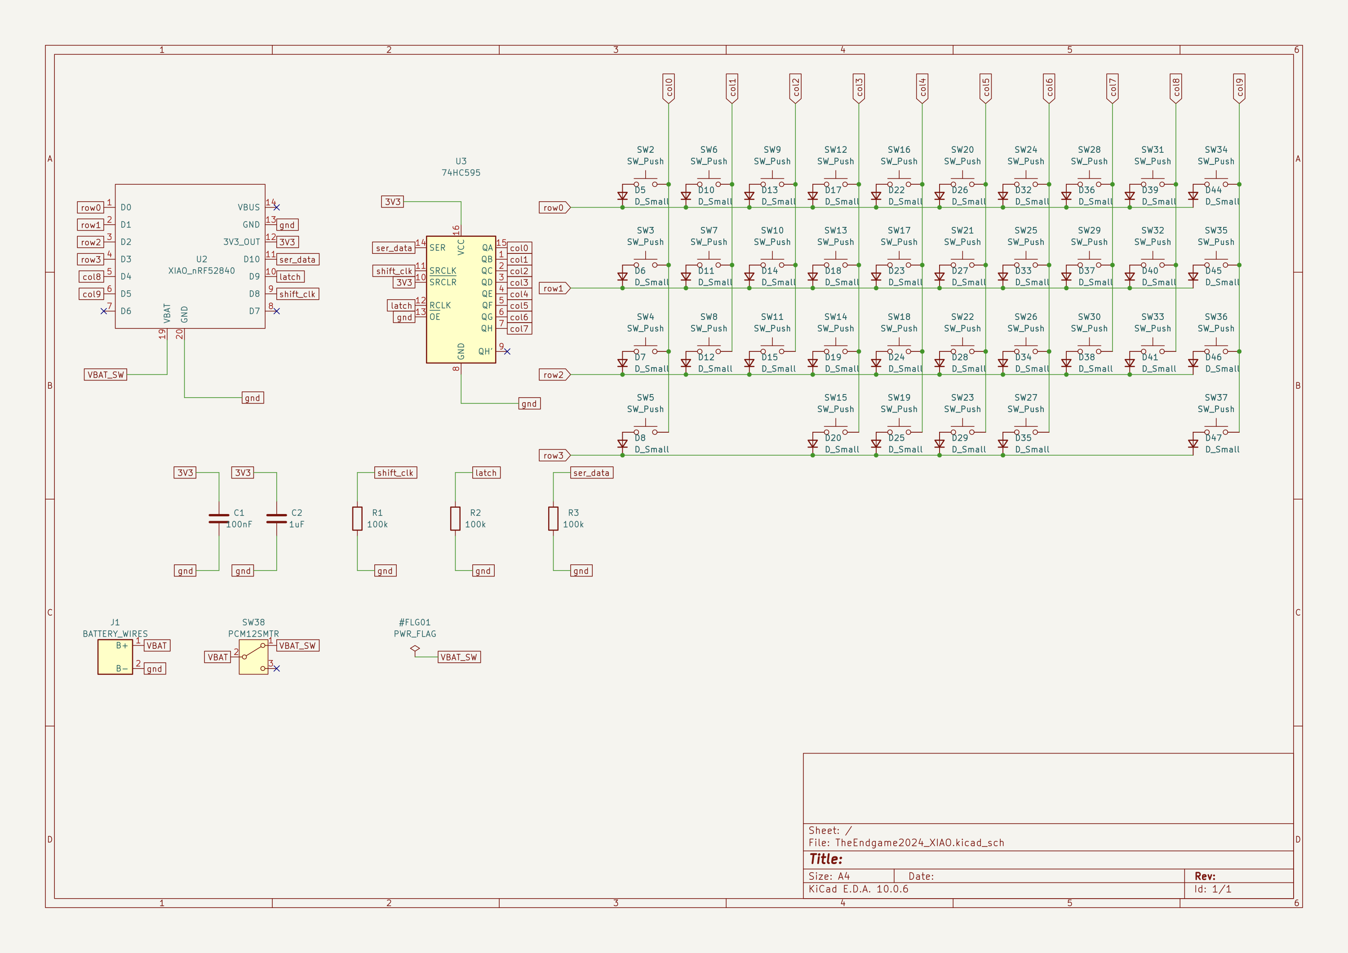
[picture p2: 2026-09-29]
docs/validation/xiao-schematic/TheEndgame2024_XIAO.png

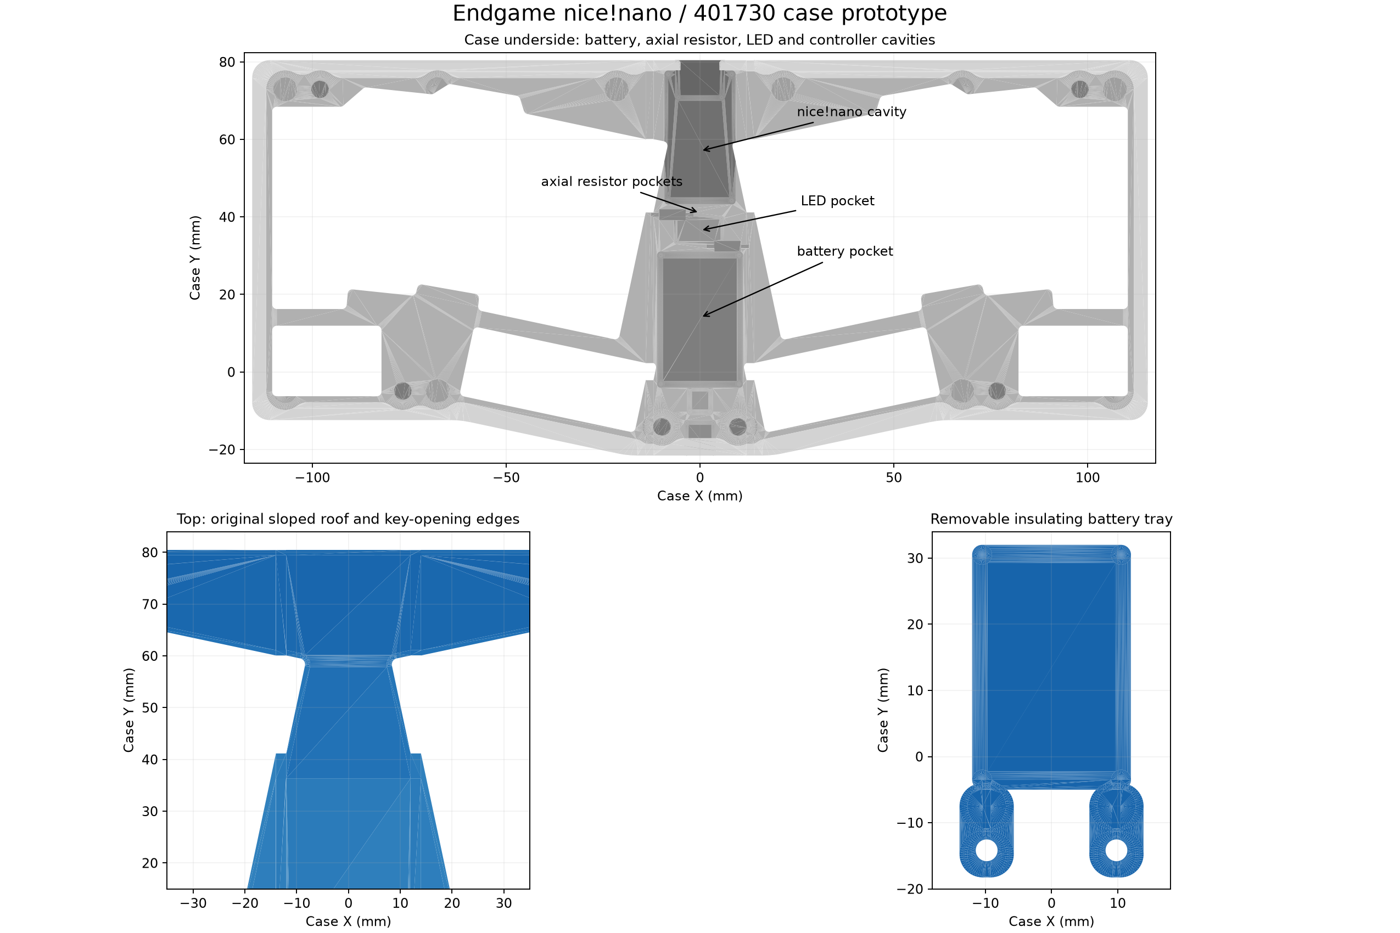
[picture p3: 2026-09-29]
002 CASE/NICE NANO WIRELESS/case-and-tray-preview.png

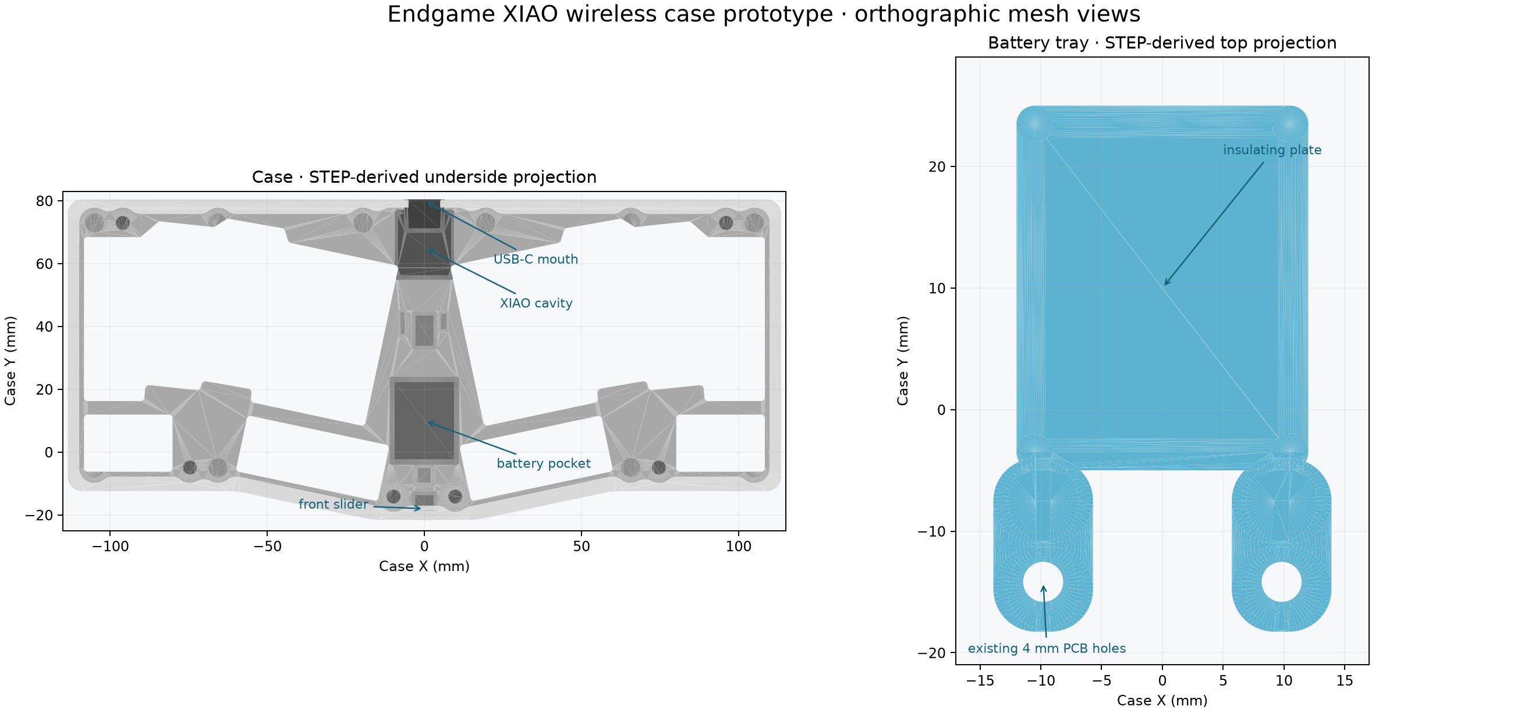
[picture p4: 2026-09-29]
002 CASE/XIAO WIRELESS/case-and-tray-preview.png

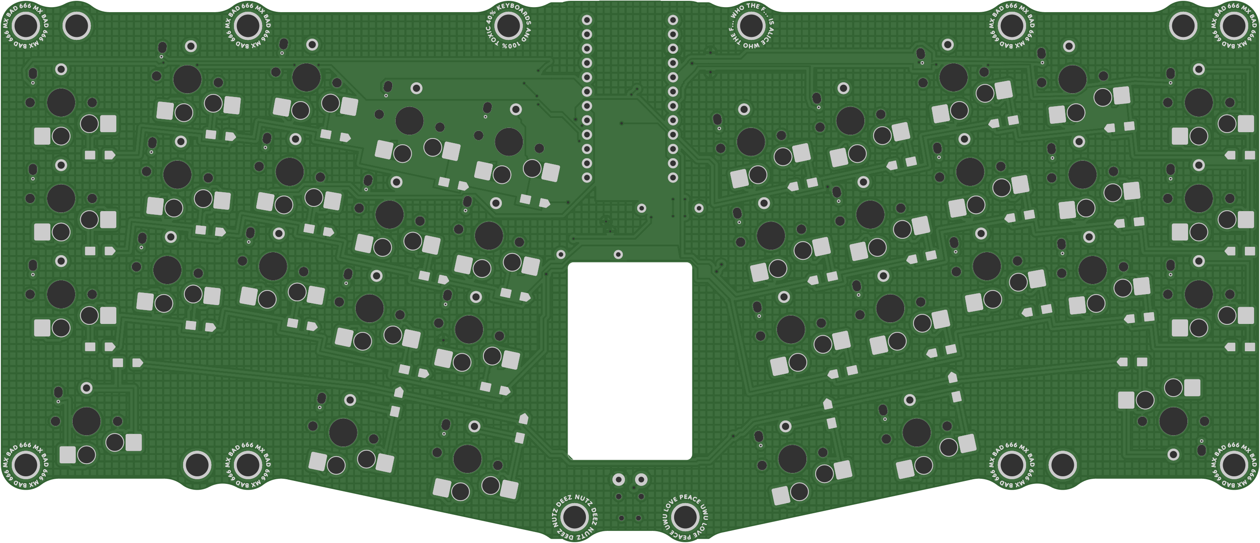
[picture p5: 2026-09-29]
001 PCB/GERBER/NICE NANO WIRELESS/back-preview.png

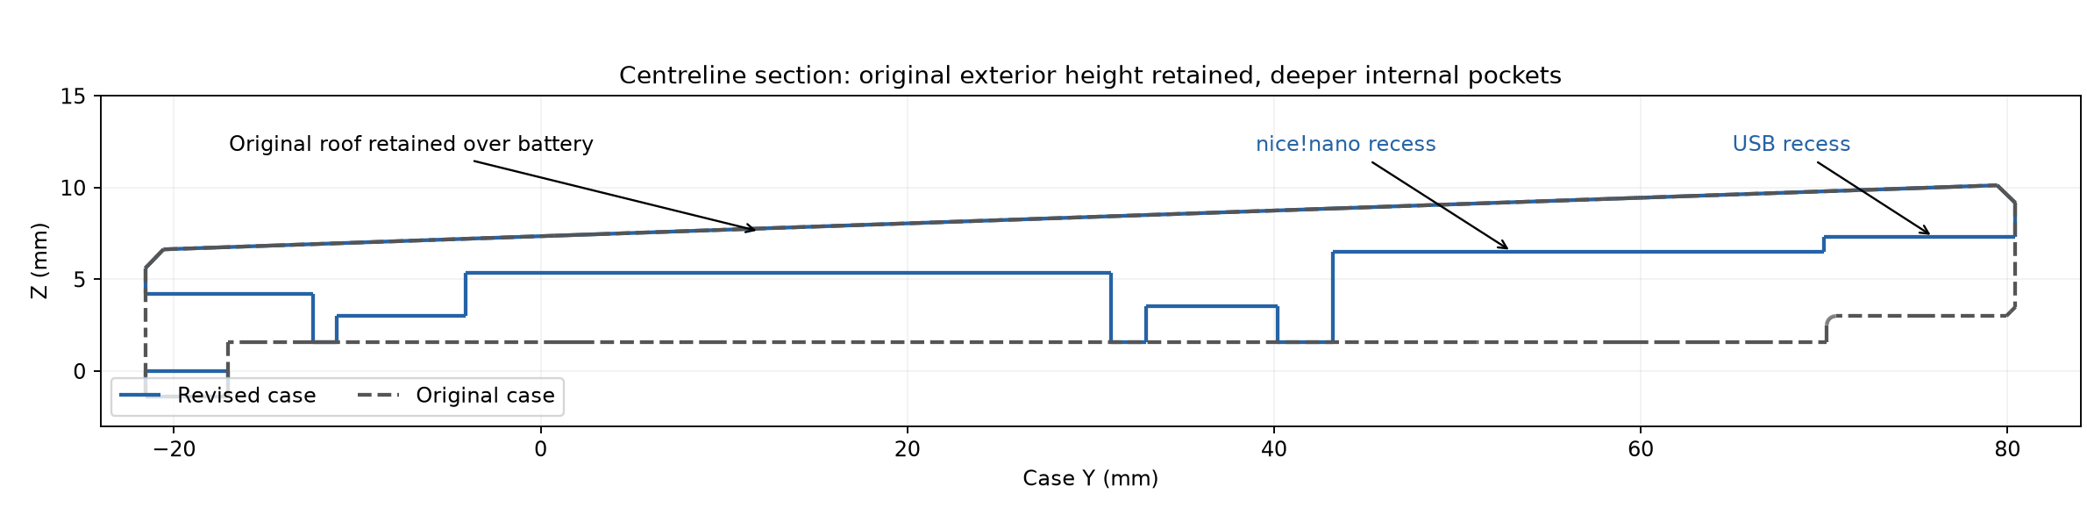
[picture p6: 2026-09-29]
002 CASE/NICE NANO WIRELESS/case-side-profile.png

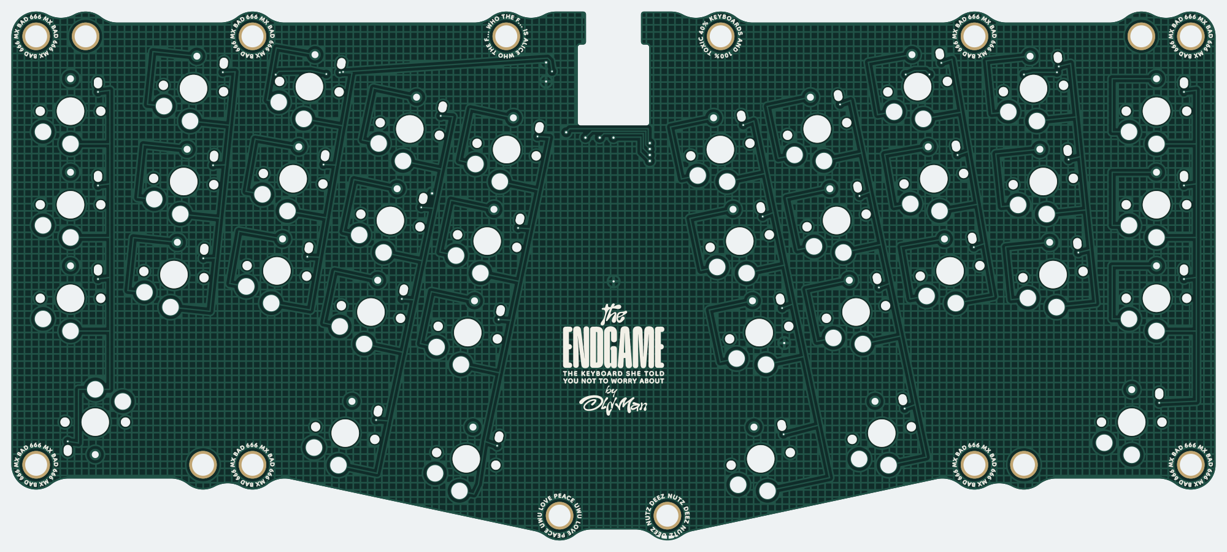
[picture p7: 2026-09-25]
001 PCB/GERBER/CHOC V1 V2/top-preview.png

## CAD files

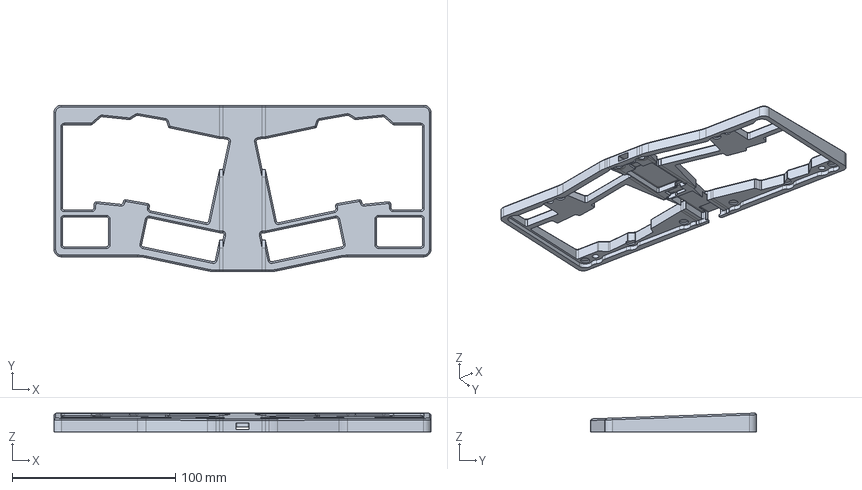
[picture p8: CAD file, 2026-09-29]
002 CASE/NICE NANO WIRELESS/TheENDGAME2024_NICE_NANO_CASE.step
231.0 x 102.0 x 11.5 mm

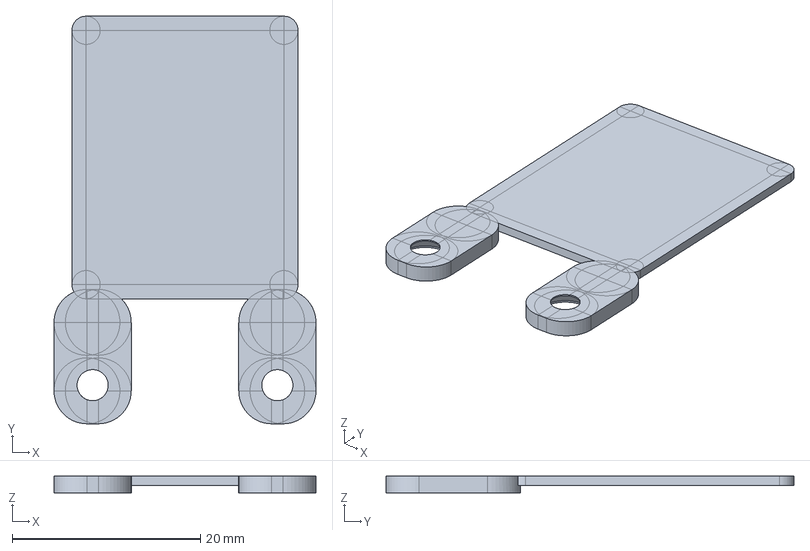
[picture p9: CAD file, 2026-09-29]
002 CASE/XIAO WIRELESS/TheENDGAME2024_XIAO_BATTERY_TRAY.step
27.8 x 43.3 x 1.80 mm

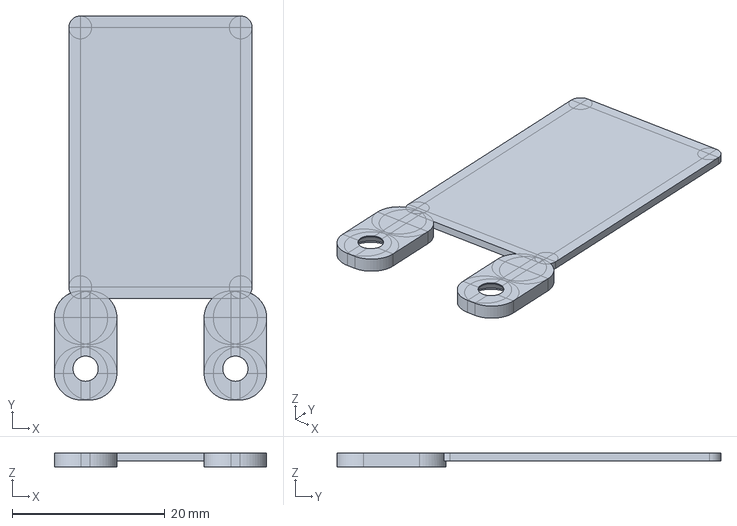
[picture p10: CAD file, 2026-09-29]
002 CASE/NICE NANO WIRELESS/TheENDGAME2024_NICE_NANO_BATTERY_TRAY.step
27.8 x 50.3 x 1.80 mm

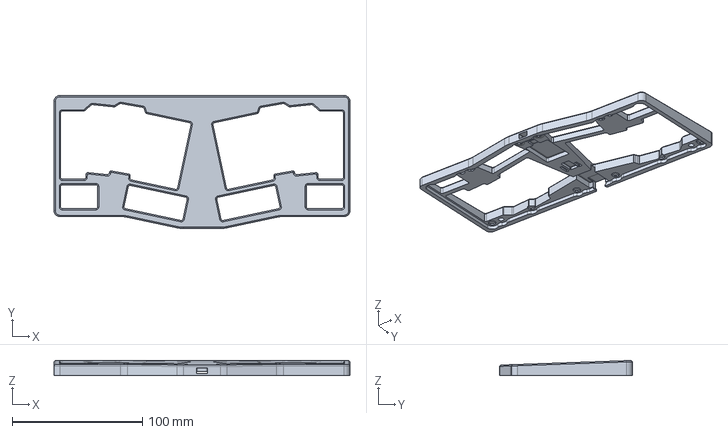
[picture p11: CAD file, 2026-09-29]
002 CASE/XIAO WIRELESS/TheENDGAME2024_XIAO_CASE.step
227.0 x 102.0 x 11.5 mm

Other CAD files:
002 CASE/NICE NANO WIRELESS/TheENDGAME2024_NICE_NANO_BATTERY_TRAY.stl
002 CASE/NICE NANO WIRELESS/TheENDGAME2024_NICE_NANO_CASE.stl
002 CASE/XIAO WIRELESS/TheENDGAME2024_XIAO_BATTERY_TRAY.stl
002 CASE/XIAO WIRELESS/TheENDGAME2024_XIAO_CASE.stl

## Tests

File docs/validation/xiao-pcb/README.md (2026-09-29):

# XIAO wireless prototype validation

The editable PCB is `001 PCB/KICAD/XIAO WIRELESS/TheEndgame2024_XIAO.kicad_pcb`. Its fabrication ZIP is `001 PCB/GERBER/XIAO WIRELESS/TheEndgame2024_XIAO_Choc_V1_V2_JLCPCB.zip`. These are a digitally checked prototype design; no physical board has been built or tested.

- **KiCad 10.0.6:** full-source DRC after zone refill/save reported 0 violations, 0 unconnected items, and 0 schematic parity issues. See [drc.json](drc.json). Schematic ERC reported 0 violations in [erc.json](../xiao-schematic/erc.json).
- **Geometry/netlist:** [geometry.json](geometry.json) records the final PCB checksum and every expected drill. All 36 switch footprints, 36 diodes, and original mechanical footprints retain their exact native positions, orientations, pad geometry, and nets. All 191 exported schematic terminals match the PCB. Specctra placement rounding was removed before this comparison. The board is 1.6 mm thick.
- **Gerber/drill parsing:** Gerbonara 1.6.3 independently opened the ZIP and checked seven graphic layers, separate plated/non-plated Excellon files, and a Gerber job file. All 215 plated drills and 148 non-plated holes/slots match the PCB within 0.002 mm. This includes 36 five-millimetre switch centres, 72 Choc V1 locators, and 36 Choc V2 1.5 × 2 mm slots. See [gerbers.json](gerbers.json).
- **Profile:** three closed contours were found: the outer perimeter, 22 × 28 mm R1 battery opening, and 3.7 × 4.15 mm XIAO battery-contact access opening. Board dimensions, including arc extrema and excluding the plotted line width, are **219.000032 × 96.106071 mm**. Use **219 × 96.11 mm** if a quote requires manual dimensions. The Gerber preview was visually inspected on both sides. The JLCPCB web upload/automatic preview has not been tested for this ZIP.
- **Case:** the CAD generator checks valid single solids, component-envelope clearance, all 36 switch-body envelopes, battery-pocket roof thickness, heat-set seats, and recessed tray fasteners. STEP reimport and STL watertightness checks also passed. See [case notes](../../xiao-case.md) for the assumed USB/module heights and required feet.
- **Firmware:** a clean ZMK build passed against pinned revision `5b51501fead672c41b5cfb396f3dafe0894bf4e9`, with the bundled shift-register interrupt patch. The UF2 SHA-256 is `897c32f8a1b893bbe501ab9a0d06c69f7789baa9a00c9becead28bae97b8d03e`. See [firmware notes](../../xiao-firmware.md).

The checks can be repeated using `tools/verify_xiao_pcb.py` with KiCad's pcbnew Python and an XML netlist exported from the final schematic, then `tools/verify_xiao_gerbers.py` with Gerbonara. `tools/export_jlcpcb.py` regenerates the manufacturing ZIP from the saved PCB. Its output directory must be new. `tools/build_xiao_pcb.py` is a placement/routing starting-point generator, not a regeneration of the finished hand-reviewed PCB; use a scratch output path.

Physical prototype tests remain: switch and socket fit, USB plug clearance, battery dimensions and retention, insulation/strain relief, both XIAO underside jumpers, all keys/rollover, Bluetooth range/pairing, idle/sleep/wake behavior, battery sensing, and the intended approximately 50 mA charging current. These checks cannot establish enclosure fit or electrical/RF performance without assembled hardware.

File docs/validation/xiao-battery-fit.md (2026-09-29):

# XIAO nRF52840 battery fit study (2026-09-28)

Historical study: the [implemented wireless prototype](../xiao-wireless.md) supersedes these provisional assembly details. The final design removes BZ2, moves the battery pads and relief holes 0.5 mm toward the opening, rounds its corners, and provides a separate revised case and tray. Use the current [case notes](../xiao-case.md) and [electrical notes](../xiao-electrical.md) for assembly.

This is a measured **candidate for the next PCB and case revision**, not a fabricated layout or a physical battery fit. The source PCB and STEP case remain unchanged. Coordinates below use the KiCad board system in millimetres; the registered case coordinates are `(board X − 150, 140 − board Y, Z)`, with the board bottom at `Z=0` and top at `Z=1.6`. The XIAO nRF52840 is intended for the existing top-centre controller region; its new footprint, USB cutout, charger, and electrical routing are outside this geometric check.

## Recommended opening and wire landing

Reserve a **22.0 × 28.0 mm rectangular PCB opening**, `X=139.0…161.0`, `Y=116.0…144.0`, centred at `(150,130)`. The corresponding case window is `X=−11.0…11.0`, `Y=−4.0…24.0`. Its long axis runs front to back. This is sized around [Adafruit 1317](https://www.adafruit.com/product/1317), a protected 150 mAh LiPo nominally **19.75 × 26.02 × 3.8 mm**, using a conservative **22 × 28 × 5 mm** pack/tape envelope. Nominal in-plane margin is 1.125 mm per side and 0.99 mm at each end. **The pack sits through the PCB plane**, with a candidate vertical envelope of `Z=0.2…5.2`; the PCB itself occupies `Z=0…1.6`. Measure the actual purchased pouch, protection circuit, tabs, and taped lead exit before finalizing a board slot.

Keep BZ2 in its current location. Orient the pack so its leads leave the opening at the `Y=144` end. For **direct soldering, without a JST connector**, provision labelled B+ and B− pads centred provisionally at `(148,148)` and `(152,148)`, each approximately 2 mm in diameter, with two 1 mm wire strain-relief holes centred at `(148,151)` and `(152,151)`. Add a shallow wire bend/channel in the revised case at the lower end of the pouch; the lead and its insulation must not be pinched by the case. These pad and relief coordinates are geometric reservations only. Final pad size, polarity, trace route to the XIAO charging circuit, hole plating, insulation, and strain-relief method need electrical and manufacturing review.

## Measured clearances on the current board

| Check | Result for proposed opening | Basis |
| --- | ---: | --- |
| Existing 36 switch centres/angles | Unchanged | Original PCB, including Choc V1/V2 hot-swap footprints |
| Nearest switch-body envelope | **6.61 mm** to SW18/SW22 | Conservative 15 × 15 mm square rotated with each switch |
| BZ2 courtyard | **3.05 mm** | Bottom-side courtyard reaches `Y=112.95`; opening begins at `Y=116` |
| Two lower mounting features | **5.17 mm** from assumed 5 mm radius | Centres `(140.195,154.17)` and `(159.805,154.17)` |
| PCB outline | **12.67 mm** minimum | KiCad board polygon; all 616 mm² of opening lies in existing laminate |
| Discrete pads, routed tracks, vias | **0 intersect** | KiCad geometry intersected with the exact opening |
| Ground zone | Spans area | Must be repoured around the new opening, with manufacturing edge clearance |
| Proposed wire pad / relief locations | No existing pads or tracks within 1 mm | All four provisional centres lie within board outline |

The switch figure concerns body envelopes, not solder pads alone. The opening is also clear of the original hot-swap socket pads and drilled holes. It leaves room for the 36 original switch positions and their V1/V2 compatibility to be carried into a new revision, subject to a complete PCB DRC after routing.

## Case comparison and vertical stack

The current STEP case is **solid from `Z=1.6…5.2`** throughout the proposed window. Its intersection with the inset 22 × 28 × 5 mm battery box at `Z=0.2…5.2` is **2,217.6 mm³**, exactly the overlapping 3.6 mm of height. The case needs a **3.6 mm deep pocket from its board-facing surface**, alongside the PCB through-hole. A Boolean check finds full case material across the entire 22 × 28 mm rectangle through `Z=6.70`; the outer surface first appears within `Z=6.70…6.75`. Thus the nominal inset pocket leaves **at least 1.50 mm of case roof** over the complete rectangle. The earlier above-PCB stack (`Z=1.6…6.6`) would have left only about 0.2 mm locally and is not the selected design.

For the case revision, cut the pocket to at least `Z=5.2` plus verified assembly clearance and provide a separate lead channel. The 1.50 mm roof result applies to the **nominal 22 × 28 mm rectangle only**; expanding the case cavity for printing tolerance or increasing its depth can reduce the minimum, so rerun the Boolean and wall-thickness check on the finished STEP model. A raised top cover is **not required by this nominal inset stack**. An insulating, load-bearing **bottom tray or cover beneath the PCB opening** is still needed to retain and protect the pouch. No case material supports the centre opening below the board. The tray and its fasteners must clear the desk or enclosure base, avoid the pouch and nearby mount features, and preserve battery service access. A 0.5 mm tray extending below `Z=0` would reach `Z=−0.5`; the STEP case has a global minimum `Z≈−1.4`, but that alone does not establish a safe desk clearance or support stiffness. Check the revised case and tray together, then print and assemble a battery dummy before committing hardware. Keep the pouch free of screw and switch loading, and allow for normal swelling and tape.

## Method and remaining gates

The board was read with KiCad 10 `pcbnew`; its outline, pads, tracks, vias, and zone were evaluated in the candidate rectangle. Switch body squares and clearance distances were calculated with Shapely. The original STEP case was read with OpenCascade (`cadquery-ocp` 8.0.1.0.0); [the case check script](../../tools/assess_xiao_battery_fit.py) reproduces the battery intersection and roof bound (`python tools/assess_xiao_battery_fit.py` in an environment with OCP). See [the plan view](xiao-battery-fit.svg) for the local layout. None of these checks accounts for conductor bend radius, battery swelling, a built-up tape seam, charger routing, assembly access, case print tolerance, or real enclosure stiffness. Before fabrication, make the new PCB opening/case pocket and lower tray, add battery protection/charge wiring and marked polarity, run KiCad DRC, recheck STEP clearance and minimum wall, then prototype with the actual pack.

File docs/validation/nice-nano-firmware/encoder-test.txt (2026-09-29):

258 frames: GRB order, pulse timings, and final low level passed

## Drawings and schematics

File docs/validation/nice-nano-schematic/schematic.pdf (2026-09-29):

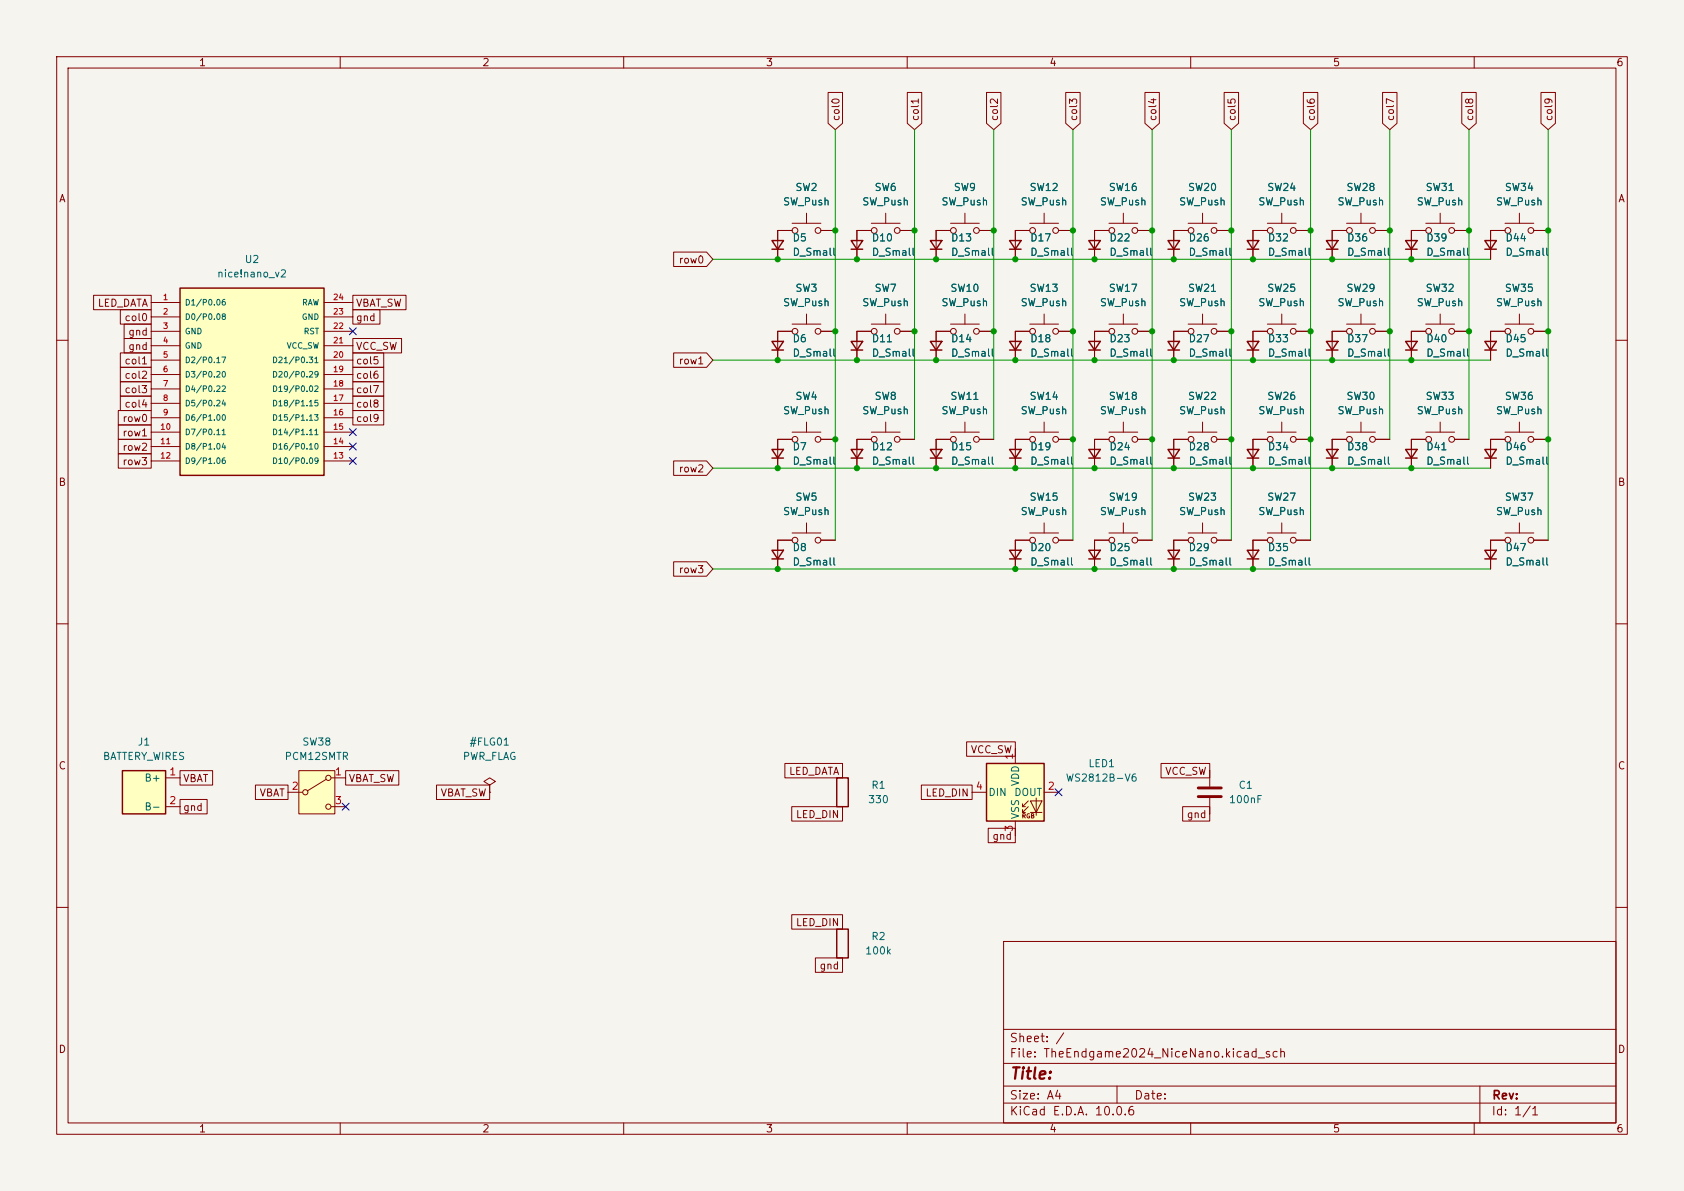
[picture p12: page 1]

Size: A4 | Rev:
KiCad E.D.A. 10.0.6 | Id: 1/1

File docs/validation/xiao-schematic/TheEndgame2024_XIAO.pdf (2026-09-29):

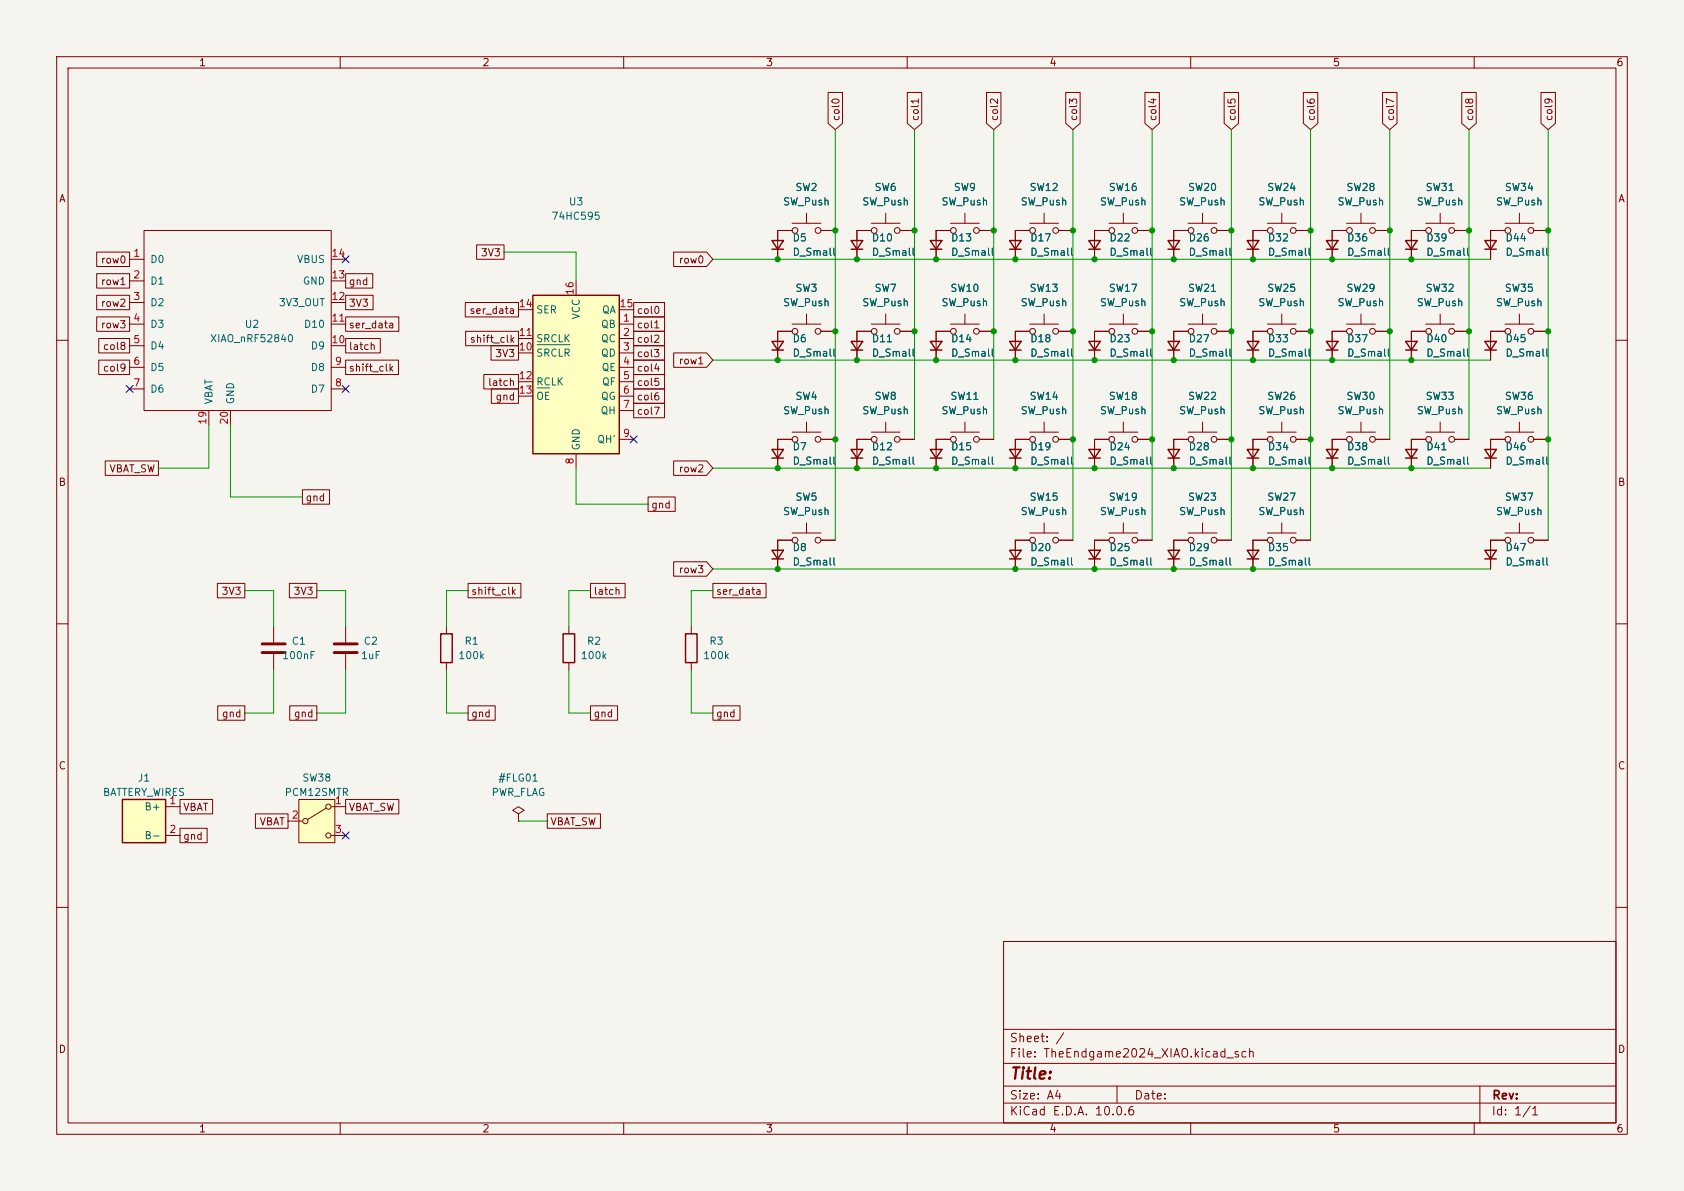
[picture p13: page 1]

SRCLR 10 SRCLK 11 RCLK 12 OE 13

Size: A4 | Rev:
KiCad E.D.A. 10.0.6 | Id: 1/1

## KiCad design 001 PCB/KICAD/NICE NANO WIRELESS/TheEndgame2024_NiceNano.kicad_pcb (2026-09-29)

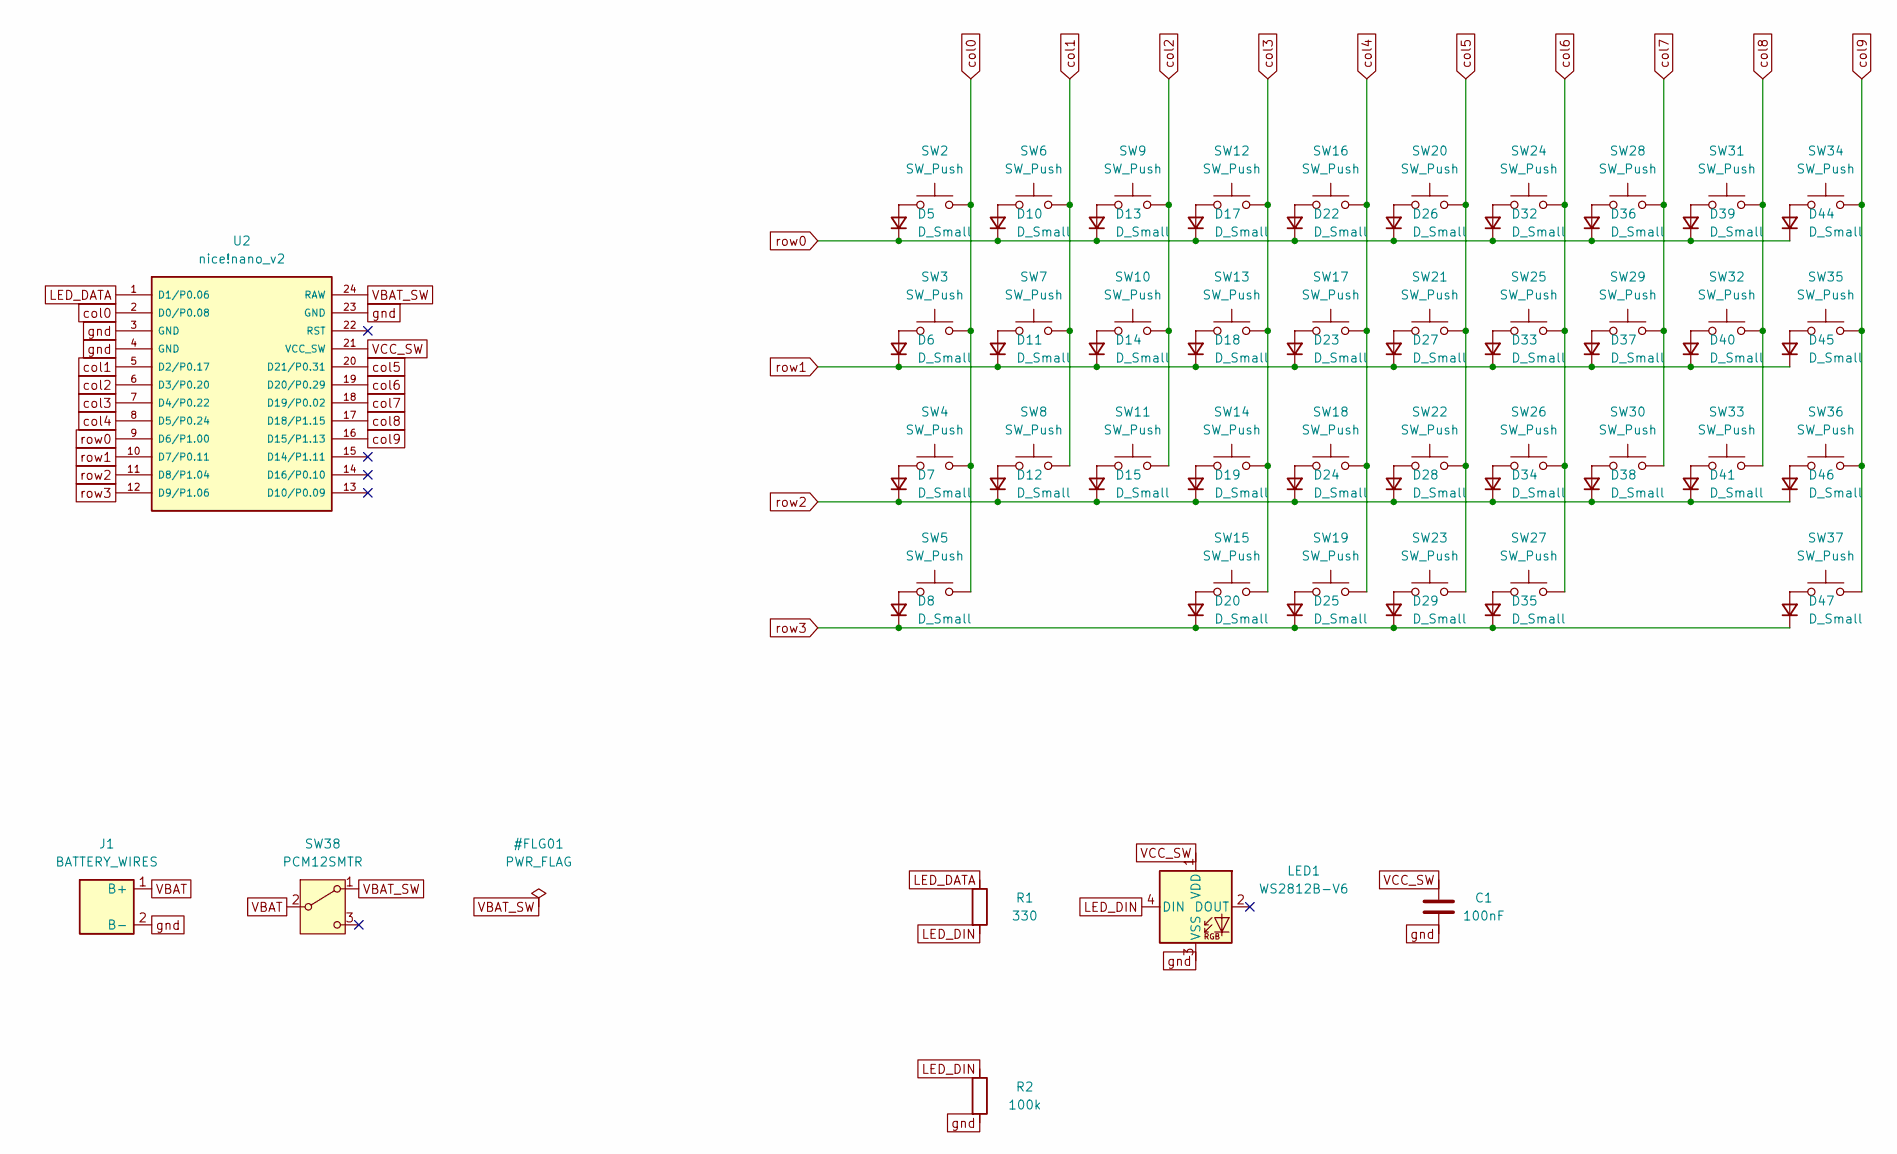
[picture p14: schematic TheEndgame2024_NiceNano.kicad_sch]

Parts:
C1: 100nF; C_0603_1608Metric
D5, D6, D7, D8, D10, D11, D12, D13, D14, D15, D17, D18, D19, D20, D22, D23, D24, D25, D26, D27, D28, D29, D32, D33, D34, D35, D36, D37, D38, D39, D40, D41, D44, D45, D46, D47: D_Small; Diode_SOD123 filets triangle
J1: BATTERY_WIRES; Battery_Wire_Pads
LED1: WS2812B-V6; WS2812B_V6_5050
R1: 330; R_Axial_DIN0207_L6.3mm_D2.5mm_P10.16mm_Horizontal
R2: 100k; R_Axial_DIN0207_L6.3mm_D2.5mm_P10.16mm_Horizontal
SW2, SW3, SW4, SW6, SW7, SW8, SW9, SW10, SW11, SW12, SW13, SW14, SW15, SW16, SW17, SW18, SW20, SW21, SW22, SW24, SW25, SW26, SW27, SW28, SW29, SW30, SW31, SW32, SW33, SW34, SW35, SW36: SW_Push; SW_choc_v1_v2_HS_1u
SW5, SW19, SW23, SW37: SW_Push; SW_choc_v1_v2_HS_1.5u
SW38: PCM12SMTR; PowerSwitch_PCM12
U2: nice!nano_v2; NiceNano_v2_PinPosts

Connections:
LED_DATA: R1.1, U2.1 (D1/P0.06)
LED_DIN: LED1.4 (DIN), R1.2, R2.1
unnamed: D5.2 (A), SW2.1
unnamed: D6.2 (A), SW3.1
unnamed: D7.2 (A), SW4.1
unnamed: D8.2 (A), SW5.1
unnamed: D10.2 (A), SW6.1
unnamed: D11.2 (A), SW7.1
unnamed: D12.2 (A), SW8.1
unnamed: D13.2 (A), SW9.1
unnamed: D14.2 (A), SW10.1
unnamed: D15.2 (A), SW11.1
unnamed: D17.2 (A), SW12.1
unnamed: D18.2 (A), SW13.1
unnamed: D19.2 (A), SW14.1
unnamed: D20.2 (A), SW15.1
unnamed: D22.2 (A), SW16.1
unnamed: D23.2 (A), SW17.1
unnamed: D24.2 (A), SW18.1
unnamed: D25.2 (A), SW19.1
unnamed: D26.2 (A), SW20.1
unnamed: D27.2 (A), SW21.1
unnamed: D28.2 (A), SW22.1
unnamed: D29.2 (A), SW23.1
unnamed: D32.2 (A), SW24.1
unnamed: D33.2 (A), SW25.1
unnamed: D34.2 (A), SW26.1
unnamed: D35.2 (A), SW27.1
unnamed: D36.2 (A), SW28.1
unnamed: D37.2 (A), SW29.1
unnamed: D38.2 (A), SW30.1
unnamed: D39.2 (A), SW31.1
unnamed: D40.2 (A), SW32.1
unnamed: D41.2 (A), SW33.1
unnamed: D44.2 (A), SW34.1
unnamed: D45.2 (A), SW35.1
unnamed: D46.2 (A), SW36.1
unnamed: D47.2 (A), SW37.1
VBAT: J1.1 (B+), SW38.2 (B)
VBAT_SW: SW38.1 (A), U2.24 (RAW)
VCC_SW: C1.1, LED1.1 (VDD), U2.21 (VCC_SW)
col0: SW2.2, SW3.2, SW4.2, SW5.2, U2.2 (D0/P0.08)
col1: SW6.2, SW7.2, SW8.2, U2.5 (D2/P0.17)
col2: SW9.2, SW10.2, SW11.2, U2.6 (D3/P0.20)
col3: SW12.2, SW13.2, SW14.2, SW15.2, U2.7 (D4/P0.22)
col4: SW16.2, SW17.2, SW18.2, SW19.2, U2.8 (D5/P0.24)
col5: SW20.2, SW21.2, SW22.2, SW23.2, U2.20 (D21/P0.31)
col6: SW24.2, SW25.2, SW26.2, SW27.2, U2.19 (D20/P0.29)
col7: SW28.2, SW29.2, SW30.2, U2.18 (D19/P0.02)
col8: SW31.2, SW32.2, SW33.2, U2.17 (D18/P1.15)
col9: SW34.2, SW35.2, SW36.2, SW37.2, U2.16 (D15/P1.13)
gnd: C1.2, J1.2 (B-), LED1.3 (VSS), R2.2, U2.3 (GND), U2.4 (GND), U2.23 (GND)
row0: D5.1 (K), D10.1 (K), D13.1 (K), D17.1 (K), D22.1 (K), D26.1 (K), D32.1 (K), D36.1 (K), D39.1 (K), D44.1 (K), U2.9 (D6/P1.00)
row1: D6.1 (K), D11.1 (K), D14.1 (K), D18.1 (K), D23.1 (K), D27.1 (K), D33.1 (K), D37.1 (K), D40.1 (K), D45.1 (K), U2.10 (D7/P0.11)
row2: D7.1 (K), D12.1 (K), D15.1 (K), D19.1 (K), D24.1 (K), D28.1 (K), D34.1 (K), D38.1 (K), D41.1 (K), D46.1 (K), U2.11 (D8/P1.04)
row3: D8.1 (K), D20.1 (K), D25.1 (K), D29.1 (K), D35.1 (K), D47.1 (K), U2.12 (D9/P1.06)

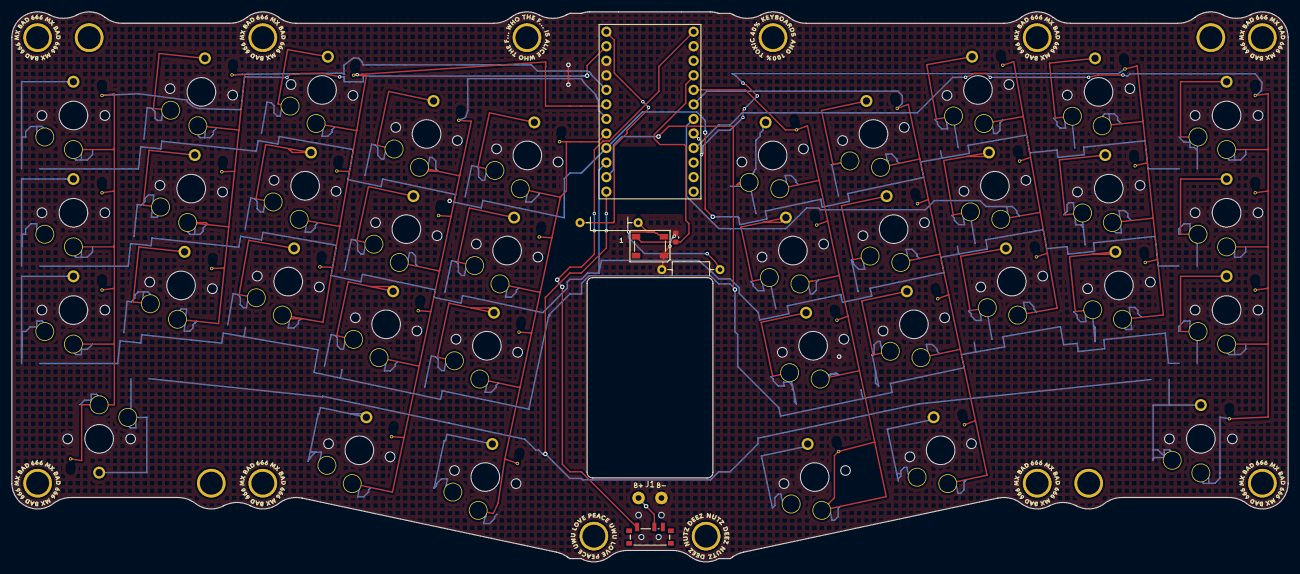
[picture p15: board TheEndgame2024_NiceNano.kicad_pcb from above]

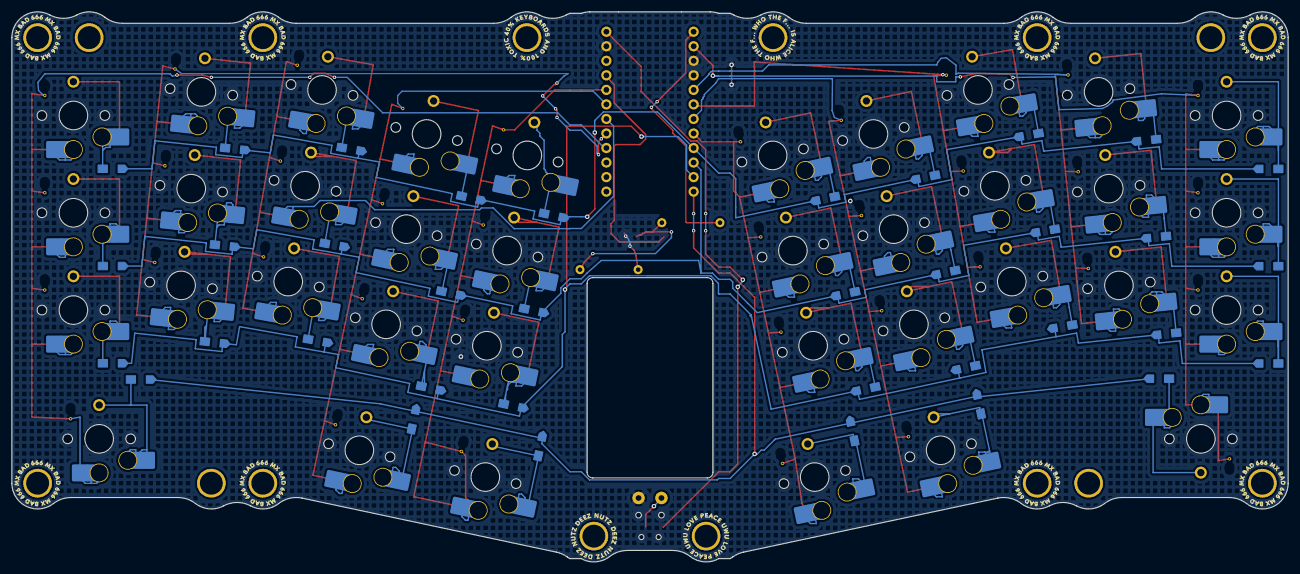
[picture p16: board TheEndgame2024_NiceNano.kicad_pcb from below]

Board: 2 copper layers, 223.0 x 96.1 mm, 79 parts (72 on the bottom side), 56 nets.

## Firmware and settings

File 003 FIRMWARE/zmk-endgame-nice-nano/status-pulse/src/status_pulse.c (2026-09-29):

/*
 * Explicit, bounded status pulse for one WS2812B on nice!nano v2 switched VCC.
 * No ZMK RGB underglow state, animation timer, or persistent power setting.
 * SPDX-License-Identifier: MIT
 */

#define DT_DRV_COMPAT zmk_behavior_endgame_status_pulse

#include <errno.h>
#include <zephyr/device.h>
#include <zephyr/devicetree.h>
#include <zephyr/drivers/gpio.h>
#include <zephyr/drivers/led_strip.h>
#include <zephyr/drivers/sensor.h>
#include <zephyr/kernel.h>
#include <zephyr/pm/device.h>
#include <zephyr/sys/util.h>

#include <drivers/behavior.h>
#include <zmk/activity.h>
#include <zmk/event_manager.h>
#include <zmk/events/activity_state_changed.h>

#include <endgame/status_pulse.h>

#define PIXEL_NODE DT_NODELABEL(status_pixel)
#define BATTERY_NODE DT_CHOSEN(zmk_battery)

/* P0.13 is the nice!nano v2 VCC enable; P0.06 is SPI3 MOSI / LED DIN.
 * They are intentionally not shared with the matrix. */
static const struct gpio_dt_spec power = {
    .port = DEVICE_DT_GET(DT_NODELABEL(gpio0)), .pin = 13, .dt_flags = GPIO_ACTIVE_HIGH};
static const struct gpio_dt_spec din = {
    .port = DEVICE_DT_GET(DT_NODELABEL(gpio0)), .pin = 6, .dt_flags = GPIO_ACTIVE_HIGH};
static const struct device *const pixel = DEVICE_DT_GET(PIXEL_NODE);
static const struct device *const battery = DEVICE_DT_GET(BATTERY_NODE);

enum {
    PULSE_DEFAULT_MS = 100,
    PULSE_MAX_MS = 500,
    PULSE_MAX_CHANNEL = 25, /* at most 9.8% of each PWM channel */
    PULSE_MIN_BATTERY_MV = 3600,
};

static K_MUTEX_DEFINE(pulse_lock);
static K_MUTEX_DEFINE(api_lock);
static struct k_work_delayable end_work;
static bool powered;
/* Guard against an expiry work item already dequeued when a new pulse starts. */
static int64_t end_due_ms;

static int power_off_locked(void) {
    int rc = 0;
    end_due_ms = 0;

    if (powered && device_is_ready(pixel)) {
        struct led_rgb black = {0};
        rc = led_strip_update_rgb(pixel, &black, 1);
    }

    /* The last WS2812 SPI frame is zero-ended. Explicitly drive DIN low
     * before removing VCC; the PCB also has a 100 kOhm DIN pulldown. */
    int din_rc = gpio_pin_configure_dt(&din, GPIO_OUTPUT_INACTIVE);
    int power_rc = gpio_pin_set_dt(&power, 0);
    powered = false;

    if (rc != 0) {
        return rc;
    }
    return din_rc != 0 ? din_rc : power_rc;
}

static void end_work_handler(struct k_work *work) {
    ARG_UNUSED(work);
    k_mutex_lock(&pulse_lock, K_FOREVER);
    int64_t remaining = end_due_ms - k_uptime_get();
    if (end_due_ms != 0 && remaining > 0) {
        if (k_work_reschedule(&end_work, K_MSEC(remaining)) < 0) {
            (void)power_off_locked();
        }
    } else if (end_due_ms != 0) {
        (void)power_off_locked();
    }
    k_mutex_unlock(&pulse_lock);
}

int endgame_status_cancel(void) {
    k_mutex_lock(&api_lock, K_FOREVER);
    /* This may run on Zephyr's system work queue during ZMK sleep. Waiting
     * for end_work here would deadlock that queue. The mutex and deadline
     * keep cancellation ordered with a possibly running expiry handler. */
    (void)k_work_cancel_delayable(&end_work);
    k_mutex_lock(&pulse_lock, K_FOREVER);
    int rc = power_off_locked();
    k_mutex_unlock(&pulse_lock);
    k_mutex_unlock(&api_lock);
    return rc;
}

static int battery_millivolts(void) {
    if (!device_is_ready(battery)) {
        return -ENODEV;
    }
    int rc = sensor_sample_fetch_chan(battery, SENSOR_CHAN_GAUGE_VOLTAGE);
    if (rc != 0) {
        return rc;
    }
    struct sensor_value voltage;
    rc = sensor_channel_get(battery, SENSOR_CHAN_GAUGE_VOLTAGE, &voltage);
    if (rc != 0) {
        return rc;
    }
    return voltage.val1 * 1000 + voltage.val2 / 1000;
}

int endgame_status_pulse(uint8_t red, uint8_t green, uint8_t blue,
                         uint16_t duration_ms) {
    /* Fail closed when the LED supply may be below its minimum rating. The
     * built-in VDDH sensor measures supply voltage, not switched VCC. */
    int mv = battery_millivolts();
    if (mv < 0) {
        return mv;
    }
    if (mv < PULSE_MIN_BATTERY_MV) {
        return -EAGAIN;
    }
    if (!device_is_ready(pixel)) {
        return -ENODEV;
    }

    uint16_t bounded_ms = duration_ms == 0 ? PULSE_DEFAULT_MS :
                          MIN(duration_ms, PULSE_MAX_MS);
    struct led_rgb color = {
        .r = MIN(red, PULSE_MAX_CHANNEL),
        .g = MIN(green, PULSE_MAX_CHANNEL),
        .b = MIN(blue, PULSE_MAX_CHANNEL),
    };

    k_mutex_lock(&api_lock, K_FOREVER);
    (void)k_work_cancel_delayable(&end_work);
    k_mutex_lock(&pulse_lock, K_FOREVER);
    int rc;
    if (zmk_activity_get_state() == ZMK_ACTIVITY_SLEEP) {
        rc = -EAGAIN;
        goto done;
    }
    rc = power_off_locked();
    if (rc != 0) {
        goto done;
    }
    rc = gpio_pin_set_dt(&power, 1);
    if (rc != 0) {
        goto fail;
    }
    powered = true;
    k_msleep(1); /* Rail settling and more than the V6's 280 us reset time. */
    struct led_rgb black = {0};
    rc = led_strip_update_rgb(pixel, &black, 1);
    if (rc != 0) {
        goto fail;
    }
    rc = led_strip_update_rgb(pixel, &color, 1);
    if (rc != 0) {
        goto fail;
    }
    end_due_ms = k_uptime_get() + bounded_ms;
    rc = k_work_reschedule(&end_work, K_MSEC(bounded_ms));
    if (rc < 0) {
        goto fail;
    }
    rc = 0;
    goto done;

fail:
    (void)power_off_locked();
done:
    k_mutex_unlock(&pulse_lock);
    k_mutex_unlock(&api_lock);
    return rc;
}

static int pulse_init(const struct device *dev) {
    ARG_UNUSED(dev);
    if (!gpio_is_ready_dt(&power) || !gpio_is_ready_dt(&din)) {
        return -ENODEV;
    }
    int rc = gpio_pin_configure_dt(&din, GPIO_OUTPUT_INACTIVE);
    if (rc != 0) {
        return rc;
    }
    rc = gpio_pin_configure_dt(&power, GPIO_OUTPUT_INACTIVE);
    if (rc != 0) {
        return rc;
    }
    k_work_init_delayable(&end_work, end_work_handler);
    return 0;
}

static int pulse_pm_action(const struct device *dev, enum pm_device_action action) {
    ARG_UNUSED(dev);
    if (action == PM_DEVICE_ACTION_SUSPEND) {
        return endgame_status_cancel();
    }
    return action == PM_DEVICE_ACTION_RESUME ? 0 : -ENOTSUP;
}

static int pulse_pressed(struct zmk_behavior_binding *binding,
                         struct zmk_behavior_binding_event event) {
    ARG_UNUSED(binding);
    ARG_UNUSED(event);
    return endgame_status_pulse(25, 10, 0, PULSE_DEFAULT_MS);
}

static int pulse_released(struct zmk_behavior_binding *binding,
                          struct zmk_behavior_binding_event event) {
    ARG_UNUSED(binding);
    ARG_UNUSED(event);
    return ZMK_BEHAVIOR_OPAQUE;
}

static const struct behavior_driver_api pulse_api = {
    .binding_pressed = pulse_pressed,
    .binding_released = pulse_released,
    .locality = BEHAVIOR_LOCALITY_GLOBAL,
};

PM_DEVICE_DT_INST_DEFINE(0, pulse_pm_action);
BEHAVIOR_DT_INST_DEFINE(0, pulse_init, PM_DEVICE_DT_INST_GET(0), NULL, NULL,
                        POST_KERNEL, 95, &pulse_api);
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

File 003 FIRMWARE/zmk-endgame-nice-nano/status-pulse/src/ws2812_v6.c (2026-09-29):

/* SPDX-License-Identifier: MIT */
#define DT_DRV_COMPAT endgame_ws2812_v6_spi
#include <errno.h>
#include <zephyr/device.h>
#include <zephyr/drivers/led_strip.h>
#include <zephyr/drivers/spi.h>
#include <zephyr/kernel.h>
#include <endgame/ws2812_v6_encode.h>

static const struct spi_dt_spec bus = SPI_DT_SPEC_INST_GET(
    0, SPI_OP_MODE_MASTER | SPI_TRANSFER_MSB | SPI_WORD_SET(8), 0);

static int update(const struct device *dev, struct led_rgb *pixels, size_t count) {
    ARG_UNUSED(dev);
    if (count != 1) { return -EINVAL; }
    uint8_t encoded[ENDGAME_PIXEL_BYTES];
    endgame_encode_pixel(encoded, pixels[0].r, pixels[0].g, pixels[0].b);
    const struct spi_buf buffer = {.buf = encoded, .len = sizeof(encoded)};
    const struct spi_buf_set tx = {.buffers = &buffer, .count = 1};
    int rc = spi_write_dt(&bus, &tx);
    /* Last encoded bit is zero; keep MOSI low for the V6 latch interval. */
    k_usleep(300);
    return rc;
}

static size_t length(const struct device *dev) { ARG_UNUSED(dev); return 1; }
static int init(const struct device *dev) {
    ARG_UNUSED(dev);
    return spi_is_ready_dt(&bus) ? 0 : -ENODEV;
}
static DEVICE_API(led_strip, api) = {.update_rgb = update, .length = length};
DEVICE_DT_INST_DEFINE(0, init, NULL, NULL, NULL, POST_KERNEL,
                      CONFIG_LED_STRIP_INIT_PRIORITY, &api);

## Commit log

2026-06-12 Add Choc V2 clearance and JLCPCB gerbers
2026-06-12 Update README for JLCPCB gerbers
2026-09-25 Add Choc V1/V2 hot-swap support and JLCPCB fabrication package
    [TheENDGAME2024_COPPER.kicad_sch, TheENDGAME2024_SILKSCREEN.kicad_pcb, TheENDGAME2024_SILKSCREEN.kicad_sch]
2026-09-29 Start XIAO wireless branch with battery fit and direct-wire design
2026-09-29 Add XIAO wireless PCB, battery case and ZMK firmware
    [TheENDGAME2024_XIAO_BATTERY_TRAY.step, TheENDGAME2024_XIAO_BATTERY_TRAY.stl, TheENDGAME2024_XIAO_CASE.step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]
2026-09-29 Add nice!nano wireless prototype with 401730 tray and status LED
    [TheENDGAME2024_NICE_NANO_BATTERY_TRAY.step, TheENDGAME2024_NICE_NANO_BATTERY_TRAY.stl, TheENDGAME2024_NICE_NANO_CASE.step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]
2026-09-29 Restore keycap clearance at nice!nano case opening
    [TheENDGAME2024_NICE_NANO_CASE.step, TheENDGAME2024_NICE_NANO_CASE.stl]
2026-09-29 Widen key halves for controller clearance and add axial resistors
    [TheENDGAME2024_NICE_NANO_CASE.step, TheENDGAME2024_NICE_NANO_CASE.stl, TheEndgame2024_NiceNano.kicad_pcb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]
2026-09-29 Document current nice!nano build and manufacturing files
2026-09-29 Adapt RGB LED widget for brief WS2812 status flashes
2026-10-07 Add Choc V2 switch plates and prototype build notes
    Plates drop into the original case's switch wells (three pieces per side,
    left/right mirrored). The 3-D printed version fills the well from the PCB to
    the switch flange with a 1.2 mm clip lip and has been test-fitted; a 1.2 mm
    FR-4/metal sheet version with JLCPCB Gerbers and DXF is also included. Both
    are generated from the KiCad switch positions and checked against the case
    STEP for zero intersection.
    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
2026-10-07 Add Choc V2 switch plates for the nice!nano case
    Regenerate the printed and 1.2 mm sheet plates for the widened nice!nano
    case and its 2 mm outward key shift. In this case the alpha wells open into
    the central controller cavity at plate height, so open-sided wells are now
    bounded 2 mm beyond their switch housings, and top-side parts (U2, LED1, C1,
    R1, R2, J1, SW38) are cleared using their courtyards via a new
    export_switches.py --keepouts option. Both plate tools take --case.
    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
2026-10-15 Refine nice!nano case thumb edges and USB clearance
2026-10-15 Document both wireless Endgame builds
2026-10-15 Clarify nice!nano case fit requirement
2026-10-16 Relieve battery tray around resistor solder joints
2026-10-17 Add clear LED logo inlay for two-filament nice!nano case
    Split the case into an opaque body and a transparent runty logo column
    that runs from the LED pocket ceiling to the roof, with a two-part 3MF
    for Bambu dual-filament printing.
2026-10-17 Remove XIAO wireless variant and macOS metadata files
    Keep the wired Choc V1/V2 and nice!nano wireless builds only. The XIAO
    board is retained as a layout source for the nice!nano PCB scripts under
    001 PCB/KICAD/NICE NANO WIRELESS/source/. Drop tracked .DS_Store files
    and ignore ._* AppleDouble files.
2026-10-17 List the clear LED logo case alongside the standard nice!nano case
2026-10-17 Add ZMK firmware with a sample keymap for the RP2040-Zero Choc V2 build
    Config, board definition, shield and a generic QWERTY sample keymap,
    pinned to the same ZMK revision as the nice!nano build, plus prebuilt
    UF2s and a build script that works with a bare arm-none-eabi toolchain.
2026-10-17 Remove personal Philyoku firmware and references
    Drop the Philyoku nice!nano UF2 and its validation report, and the README,
    firmware-notes and update-note sections that described it. The generic
    sample-keymap UF2 remains the published nice!nano firmware.
2026-10-17 Restore original inner alpha opening edges on the nice!nano case
    The X=±12 widening split left the upper inner alpha-opening edges in the
    fixed centre, cutting a notch beside the top inner keys. Restore those
    strips from the original case, translated with each half, above Z=4 so
    the existing plates still fit and the controller pocket stays clear.
    Keycap clearance is now checked per key against the stock case on the
    stock PCB (0.704 mm minimum, unchanged). Rebuild the LED logo case.
2026-10-17 Hollow out the opaque material under the LED logo
    Cut a light chamber below Z=3.55 under the logo's outline plus 0.5 mm,
    joining the LED pocket, so no stroke is shadowed by opaque case material.
    The ring's inner island is now held by the clear part.
2026-10-18 Add nice!nano + Cirque touchpad PCB (239 mm, JLCPCB assembly)
    Widen the routed nice!nano board a further 8 mm per half, add a bottom-side
    12-pin FFC connector for a Cirque TM040040 (I2C on D14/D16, DR on D10) with
    4.7k pull-ups and decoupling, move the WS2812B-V6 to the right thumb gap,
    switch R1/R2 to 0603, and route the new nets with a small grid router.
    KiCad DRC: 0 errors, 0 unconnected, 0 parity issues; ERC clean. Includes
    Gerbers, LCSC BOM/CPL for JLCPCB assembly, previews and the layout sketch.
2026-10-18 Add Cirque case, tray, pad carrier and LED logo variant
    Cut a notch in the PCB battery opening for the pad's 4.1 mm FFC connector
    and re-route (DRC still clean). Build the 247 mm case by splitting the
    original at X=+-7 and moving each half 10 mm, with a flat bezel and
    chamfered collar for the TM040040 curved overlay, a printed C-ring that
    clamps the pad from below, the battery lowered 0.5 mm into a new tray, and
    the LED pocket in the right thumb gap. Every keycap keeps at least its
    stock-case clearance. The LED logo script gains a --variant option.
2026-10-18 Add Choc V2 switch plates for the nice!nano + Cirque case
    Printed and 1.2 mm sheet plates regenerated from the Cirque PCB switch
    positions and case wells (zero case intersection, >=0.3 mm clearance,
    LED/top-side parts kept clear), with JLCPCB Gerbers for the sheet plate.
2026-10-18 Add ZMK firmware for the nice!nano + Cirque Endgame
    Sample QWERTY keymap with mouse buttons and Raise-layer scrolling, Cirque
    TM040040 (Pinnacle) on I2C (D14/D16, DR on D10, NFC pins as GPIO), the
    switched VCC rail kept on while awake for the pad, a Pinnacle driver patch,
    and prebuilt keyboard and settings-reset UF2s.
2026-10-18 Move LED passives and power switch to the Cirque PCB underside
    C1/R1/R2 sit under the LED so its case pocket shrinks to the LED itself.
    SW38 moves under the nice!nano at the back edge with its slider through
    the existing USB opening, removing the case's front switch channel. The
    battery path is re-routed (0.4 mm); DRC stays clean. Previews now use the
    board's stackup colours.
2026-10-18 Recess the Cirque power switch and add photo silkscreen artwork
    Move SW38 so its slider stays 0.46 mm inside the PCB edge, re-route and
    update the case check. Add a dithered photo (0.25 mm dots) to both
    silkscreen layers, mirrored on the underside, kept clear of edges and the
    mounting-hole ring art; DRC has 0 errors. Router now ignores a net's own
    drill holes.
2026-10-18 Keep the Cirque photo artwork on the underside silkscreen only
2026-10-19 Fix pre-order review findings on the nice!nano + Cirque build
    - Reverse J2's pin order: the FFC keeps conductor order through its bend,
    so pad pin N lands on J2 pin 13-N (DR 9, SCL 4, SDA 3, GND 2, VDD 1).
    - Move J2 3.7 mm from the notch so the cable can bend; widen the notch;
    correct the AFC01 footprint (nails at +-4.45, 5.75 mm body courtyard);
    re-join the row traces it displaced.
    - Keep copper 0.2 mm from edges and 0.25 mm from holes (refilled pour).
    - Re-cut the case's front pocket to the real PCB outline (the front tabs
    overlapped the case wall by 0.48 mm) and check 0.3 mm clearance.
    - Keep the underside photo exactly 0.4 mm from edges.
    - Add paste layers to the Gerber ZIP and t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
2026-10-19 Fix second pre-order review findings on the Cirque build
    Board:
    - Extend the FFC notch to PCB X 168.9 (Y 117-129) to match where
    Cirque's drawing and photo put the pad connector (12.5-18.4 mm out,
    slot at 15.7-16.4 mm), and move J2 to X 176.0 so the cable has ~4 mm
    for its bend. Pins 1/3 and the ground via fan out under J2's body
    because SW22's socket pad sits 1 mm past the pad row.
    - Store the 0.2 mm copper-to-edge rule in the project file. The Gerber
    export refills zones with the project rules, so the shipped pour had
    run right up to the board edge.
    - Keep router vias 0.3 mm from every solder pad (two had landed in R4
    and R1 pads).
    - Keep the underside photo 0.2 mm from pad o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
2026-10-19 Fix JLCPCB rotations for bottom-side parts and flag the overlay stack
    The third pre-order review found the CPL gave bottom-side parts KiCad's
    raw rotation. JLCPCB reads bottom rotations as seen from the bottom
    (180 - KiCad's angle, as Bouni's kicad-jlcpcb-tools and bennymeg's
    Fabrication Toolkit write them), so 32 of the 36 diodes would have been
    placed backwards. The exporter now runs under KiCad's Python, writes
    180 - angle for bottom parts and places each part at the centre of its
    soldered pads (J2's origin is its pad row, 1.4 mm from its centre).
    BOM unchanged.
    Docs: Cirque's overlay drawing suggests a ~5 mm cup with the pad's PCB
    in a ~3 mm pocket, not the 1.5 mm overlay the case assum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
2026-10-21 Make the Cirque case flat on top so it prints upside down
    Drop the raised collar around the touchpad (it stood up to 0.88 mm
    above the roof) and the countersink, so the top is the original case's
    single 2-degree plane with nothing above it. The overlay's flange seat
    moves down so at least 1 mm of case remains above the flange where the
    roof is lowest; the overlay now stands proud (about 2.4 mm at the front
    of the opening, 0.8 mm at the back).
    The pad stack now uses the overlay dimensions scaled from Cirque's
    drawing (5.0 mm cup, 1.6 mm flange, pad PCB in a 3 mm pocket), and the
    carrier presses the overlay's underside. Case height and keycap
    clearances are unchanged; the case build checks th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
2026-10-30 Invert X instead of Y on the Cirque touchpad
    On the assembled board both pointer axes came out reversed with the
    Y-only inversion copied from cornecirque: the pad sits rotated 180
    degrees from the Pinnacle's own axes. Invert X only, and rebuild the
    generic UF2.
2026-10-30 Hook the Cirque battery tray over the opening's back edge
    The tray was held only by its two front screws. Its back end now has a
    12 mm-wide hook: a 0.6 mm riser through the 1 mm gap behind the battery
    and a 1 mm-thick lip lying 4 mm over the board's top face, 0.2 mm above
    it. The carrier ring gets a slot under its back for the lip.
    The tray now goes onto the board before the board goes into the case
    (slid on from 4.2 mm forward, then the front screws stop it sliding
    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
2026-11-01 README: all three PCBs take Choc V1/V2 hot-swap switches
